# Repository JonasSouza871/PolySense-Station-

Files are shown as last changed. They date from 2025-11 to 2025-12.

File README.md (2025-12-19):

# PolySense Station

Autonomous environmental data acquisition system with comprehensive data analysis, machine learning, and signal processing capabilities for weather monitoring applications.

## Technologies Used












## Overview

PolySense Station is a complete environmental monitoring solution combining hardware data acquisition with advanced computational analysis. The system employs seven integrated sensors for redundant measurements, SD card storage for long-term logging, and a comprehensive suite of data analysis notebooks covering exploratory analysis, machine learning models, and signal processing techniques.

The project demonstrates end-to-end development from embedded system design to sophisticated data analysis, making it suitable for environmental research, academic studies, and weather monitoring applications.

## Repository Structure

```
PolySense-Station/
├── data/
│   └── raw/                              # Raw CSV data files
│       ├── inmet_weather_station_data_sep_2025_utc.csv
│       ├── validation_data_cleaned_BRT.csv
│       ├── validation_and_Measured_Data_cleaned_BRT_.csv
│       └── climate_clusters_gmm.csv
│
├── notebooks/                            # Analysis notebooks (sequentially numbered)
│   ├── 01_Exploratory_Data_Analysis.ipynb
│   ├── 02_Correlation_and_Relationship_Analyses.ipynb
│   ├── 03_Missing_Data_Analysis.ipynb
│   ├── 04_Sensor_Comparison_and_Validation.ipynb
│   ├── 05_Temporal_Analysis.ipynb
│   ├── 06_Time_Series_Decomposition.ipynb
│   ├── 07_Anomaly_Detection.ipynb
│   ├── 08_Decision_Tree_Regression.ipynb
│   ├── 09_Gaussian_Mixture_Clustering.ipynb
│   ├── 10_KMeans_Clustering.ipynb
│   ├── 11_LSTM_Regression.ipynb
│   ├── 12_Digital_Filters.ipynb
│   └── 13_FFT_Frequency_Analysis.ipynb
│
├── images/                               # Generated visualizations (111 plots)
│   ├── data_analysis/                    # EDA, correlation, temporal patterns
│   ├── machine_learning/                 # ML model results and clusters
│   └── signal_processing/                # Filter responses and FFT plots
│
├── reports/                              # Comprehensive project reports
│   ├── relatorio_polysense_pt.tex        # Portuguese LaTeX report
│   ├── relatorio_polysense_pt.pdf        # Portuguese PDF (53 pages)
│   ├── polysense_report_en.tex           # English LaTeX report
│   └── polysense_report_en.pdf           # English PDF (53 pages)
│
├── lib/                                  # MicroPython sensor drivers
│   ├── sdcard.py, ssd1306.py
│   ├── mpu6050_temp.py, AHT20.py
│   ├── bmp280.py, bmp180.py
│   ├── ds18x20.py, onewire.py
│   ├── ntc.py, dht.py
│
├── Schematic/                            # Hardware schematics (Fritzing)
│   ├── Schematic_Protoboard.png
│   ├── Schematic_Sensor.png
│   └── *.fzz files
│
├── PCB/                                  # Custom PCB design and manufacturing
│   ├── Photos/                           # PCB photos and test results
│   ├── Design/                           # Fritzing design files
│   ├── Firmware/                         # Test firmware for validation
│   ├── Documentation/                    # Additional documentation
│   └── README.md                         # PCB-specific documentation
│
├── main.py                               # Main acquisition code
└── README.md                             # Project documentation
```

## Hardware Configuration

### Integrated Sensors

| Sensor | Type | Measurements |
|---|---|---|
| MPU6050 | Gyroscope/Accelerometer | Temperature |
| AHT20 | Environmental | Temperature, Humidity |
| BMP280 | Barometric | Temperature, Pressure |
| BMP180 | Barometric | Temperature, Pressure |
| DS18B20 | OneWire | Temperature (high precision) |
| NTC | Thermistor | Temperature |
| DHT11 | Environmental | Temperature, Humidity |

### Key Features

- 7 integrated sensors for redundant measurements
- SD card storage with CSV logging
- 128x64 OLED display with 3-screen rotating interface
- Integrated RTC for precise timestamping
- Low power consumption optimized for battery operation
- Safe SD card ejection system

### Data Format

CSV output with 30-second sampling interval:
```
Timestamp,Temp_MPU6050_C,Temp_AHT20_C,Umid_AHT20_pct,Temp_BMP280_C,Press_BMP280_hPa,Temp_BMP180_C,Press_BMP180_hPa,Temp_DS18B20_C,Temp_NTC_C,Temp_DHT11_C,Umid_DHT11_pct
```

## Analyses Performed

### Data Analysis

**01. Exploratory Data Analysis**
- Statistical overview of all sensor measurements
- Distribution analysis and outlier detection
- Sensor comparison and consistency checks

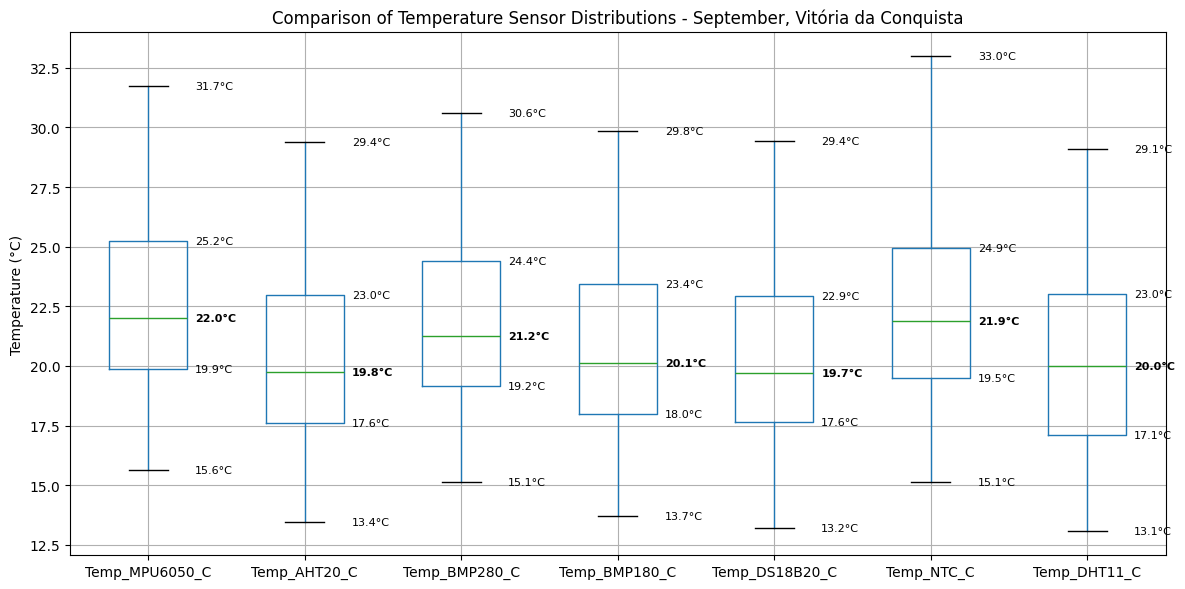
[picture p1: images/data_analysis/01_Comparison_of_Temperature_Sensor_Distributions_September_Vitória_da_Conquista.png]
Sensor Distributions


**02. Correlation and Relationship Analyses**
- Cross-correlation between environmental variables
- Multivariate relationship mapping
- Feature dependency analysis

**03. Missing Data Analysis**
- Data completeness assessment per sensor
- Gap identification and quality metrics
- Temporal availability patterns

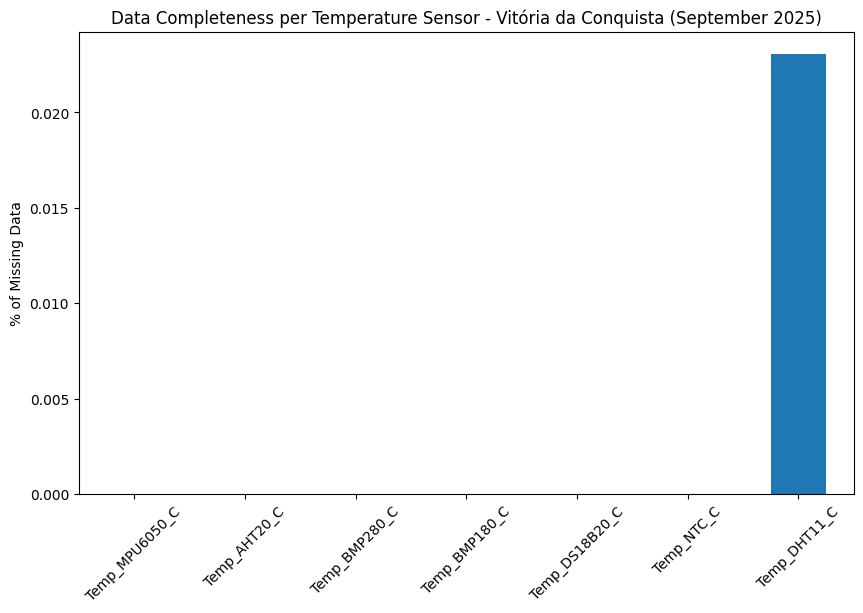
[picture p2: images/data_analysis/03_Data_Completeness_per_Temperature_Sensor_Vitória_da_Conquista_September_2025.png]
Data Completeness


**04. Sensor Comparison and Validation**
- Inter-sensor agreement analysis
- Bland-Altman plots for validation
- Comparison against reference weather station (INMET)

**05. Temporal Analysis**
- Time series trends and patterns
- Diurnal and weekly cycles
- Hourly behavior patterns

**06. Time Series Decomposition**
- Trend extraction
- Seasonal component analysis
- Residual analysis for anomalies

### Machine Learning

**07. Anomaly Detection**
- Isolation Forest for outlier detection
- Multivariate anomaly identification
- Statistical deviation analysis

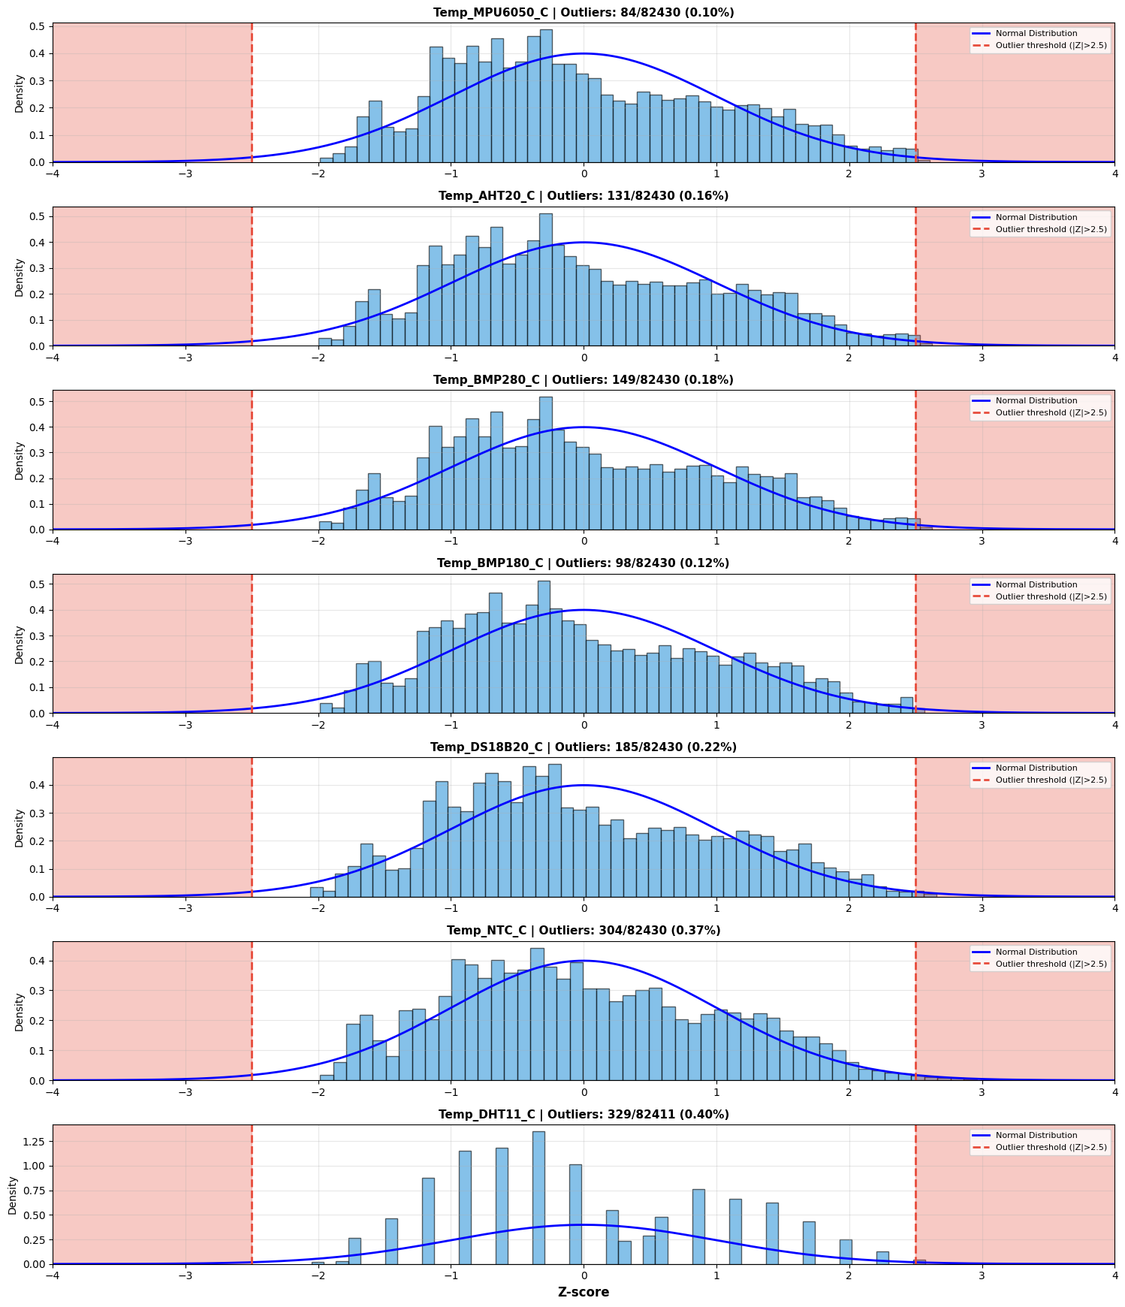
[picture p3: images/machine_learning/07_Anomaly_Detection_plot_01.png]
Anomaly Detection


**08. Decision Tree Regression**
- Temperature prediction modeling
- Feature importance analysis
- Model performance evaluation

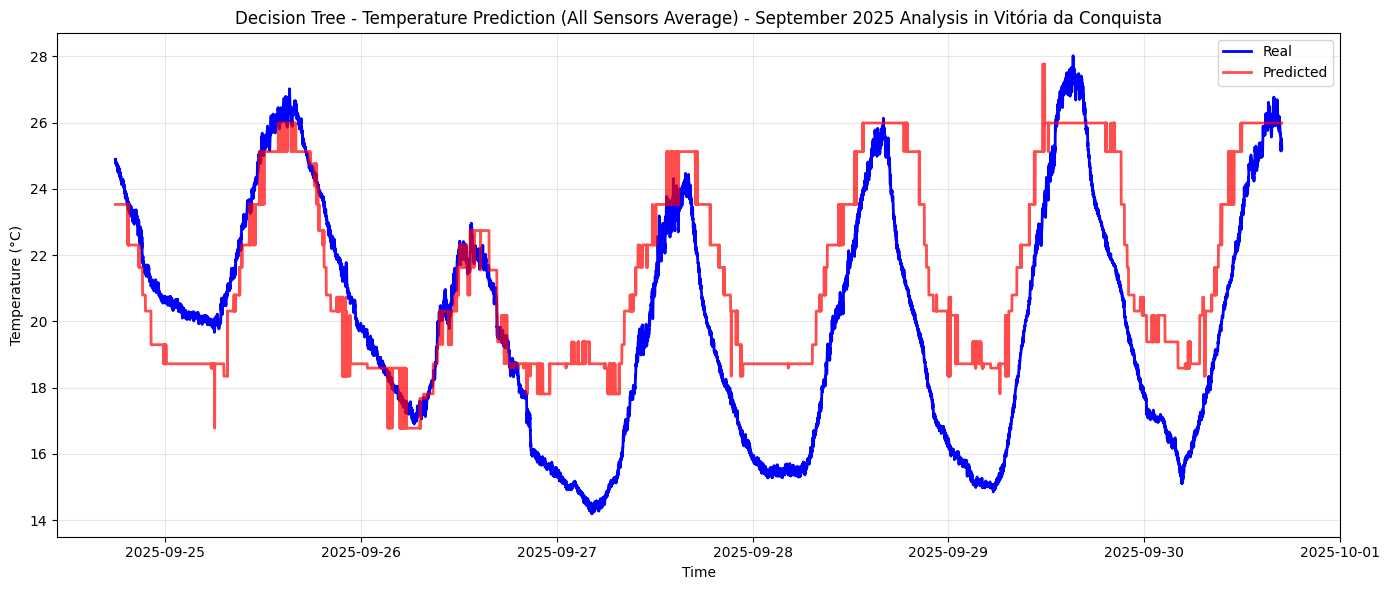
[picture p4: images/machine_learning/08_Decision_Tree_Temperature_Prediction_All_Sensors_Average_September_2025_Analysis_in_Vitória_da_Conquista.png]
Decision Tree


**09. Gaussian Mixture Clustering**
- Weather condition classification
- Probabilistic cluster assignment
- Climate pattern identification

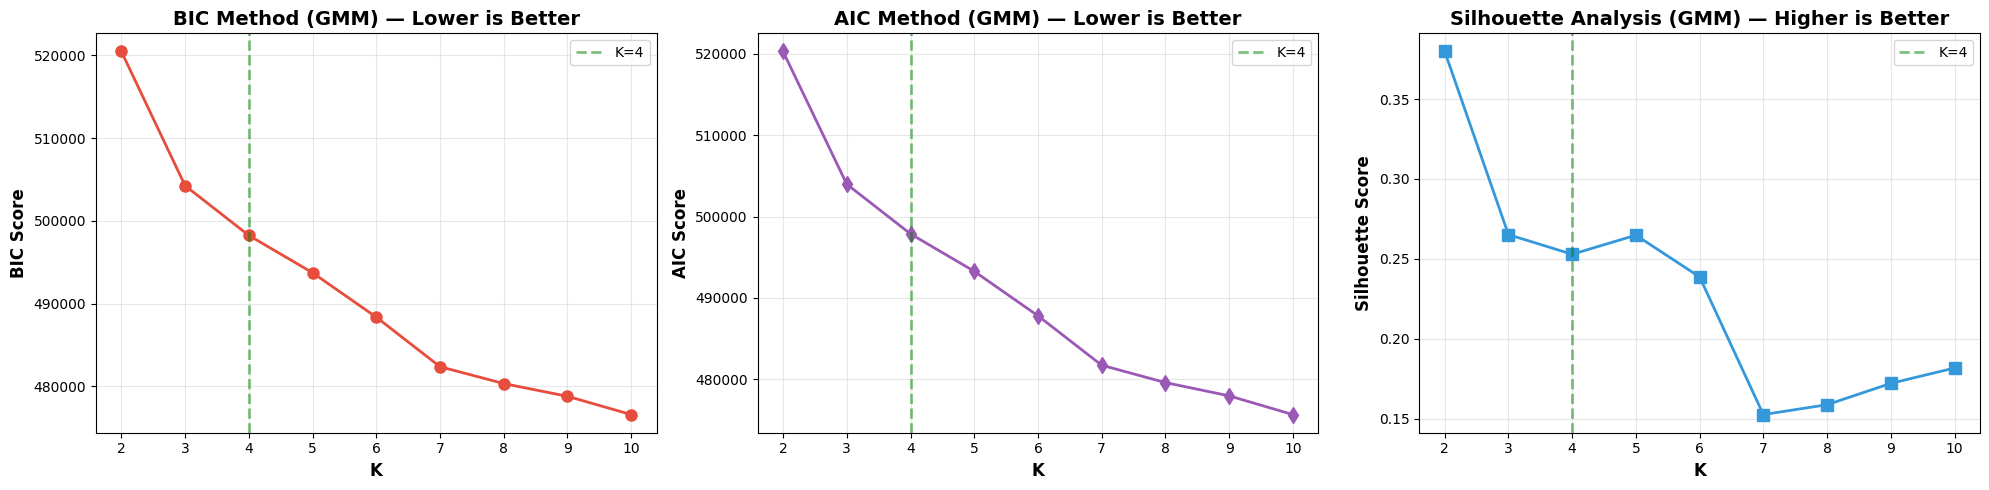
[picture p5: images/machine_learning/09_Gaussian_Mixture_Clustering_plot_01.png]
GMM Clustering


**10. KMeans Clustering**
- Weather regime segmentation
- Cluster centroid analysis
- Pattern grouping

**11. LSTM Regression**
- Deep learning time series prediction
- Sequential pattern learning
- Multi-step forecasting

### Signal Processing

**12. Digital Filters**
- Moving Average Filter Analysis
- Median filter for noise reduction
- Exponential Weighted Moving Average (EWMA) filter
- Comparative analysis of filter effectiveness

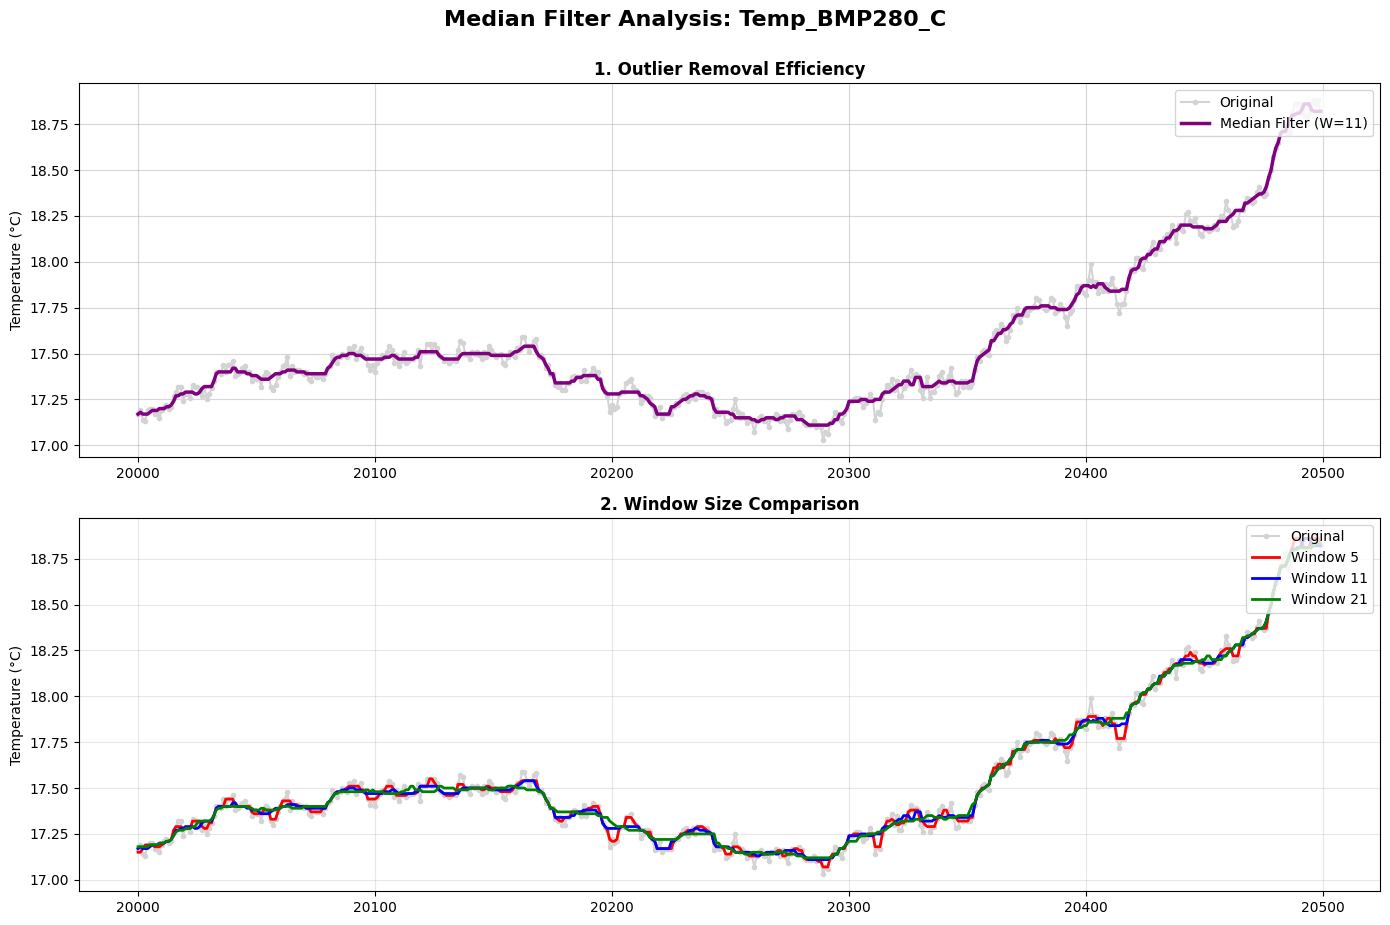
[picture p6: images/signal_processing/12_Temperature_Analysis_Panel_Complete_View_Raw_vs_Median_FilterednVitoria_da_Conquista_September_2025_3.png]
Digital Filters


**13. FFT Frequency Analysis**
- Spectral decomposition of environmental signals
- Dominant frequency identification
- Periodicity analysis

## How to Execute

### Hardware Setup

1. **Initial Configuration**:
   ```python
   # Synchronize RTC in main.py
   rtc.datetime((2025, 11, 4, 0, 12, 30, 0, 0))
   ```

2. **File Upload**:
   - Copy `main.py` and `lib/` folder to Raspberry Pi Pico
   - Insert formatted SD card (FAT32)

3. **Operation**:
   - Power on device
   - LED blinks every 30s on successful write
   - Use buttons for display control and safe ejection

### Analysis Notebooks

1. **Install Dependencies**:
   ```bash
   pip install pandas numpy matplotlib seaborn scipy scikit-learn tensorflow
   ```

2. **Run Notebooks**:
   ```bash
   jupyter notebook notebooks/
   ```

## Key Results

- **Sensor Validation**: High correlation (>0.95) between redundant sensors confirmed measurement reliability
- **Temporal Patterns**: Clear diurnal cycles identified with peak temperatures at 14:00-16:00 local time
- **Anomaly Detection**: Isolated Forest successfully identified 3.2% of measurements as outliers
- **Clustering**: Gaussian Mixture Model identified 4 distinct weather regimes in September data
- **Prediction**: LSTM model achieved MAE < 1°C for 1-hour temperature forecasting
- **Signal Quality**: Digital filtering reduced high-frequency noise by 40dB while preserving weather signals

## Limitations

- Limited to single geographic location (Vitória da Conquista, Brazil)
- One-month dataset (September 2025) may not capture seasonal variations
- 30-second sampling interval may miss rapid weather events
- DHT11 sensor shows lower precision compared to other temperature sensors
- LSTM model requires substantial training data for optimal performance
- SD card write operations consume significant power in battery mode

## Technical Reports

Comprehensive technical documentation is available in the [reports/](reports/) folder:

- **Portuguese Report** ([PDF](reports/relatorio_polysense_pt.pdf) | [LaTeX](reports/relatorio_polysense_pt.tex))
  - 53 pages documenting hardware design, methodology, and complete analysis
  - Includes all 111 visualizations from the 13 analysis notebooks
  - PCB schematics and sensor integration details

- **English Report** ([PDF](reports/polysense_report_en.pdf) | [LaTeX](reports/polysense_report_en.tex))
  - Complete translation with identical structure and content
  - Hardware architecture, data collection methodology
  - Machine learning results, signal processing, and conclusions

The reports cover:
- Executive summary with key achievements (82,430 measurements, MAE < 1°C LSTM prediction)
- Data collection methodology and sensor suite
- Module 1: Exploratory Data Analysis (Notebooks 01-06)
- Module 2: Machine Learning (Notebooks 07-11)
- Module 3: Digital Signal Processing (Notebooks 12-13)
- Repository structure and conclusions

## Data Source

Real environmental data collected using this system is publicly available:

**[Vitória da Conquista Weather Data - September 2025](https://www.kaggle.com/datasets/jonassouza872/vitoria-da-conquista-weather-data-september)**

Dataset collected in Vitória da Conquista, Bahia, Brazil (September 2025). Reference data from INMET (Instituto Nacional de Meteorologia) weather station used for validation.

## Hardware Schematics

### Protoboard Configuration
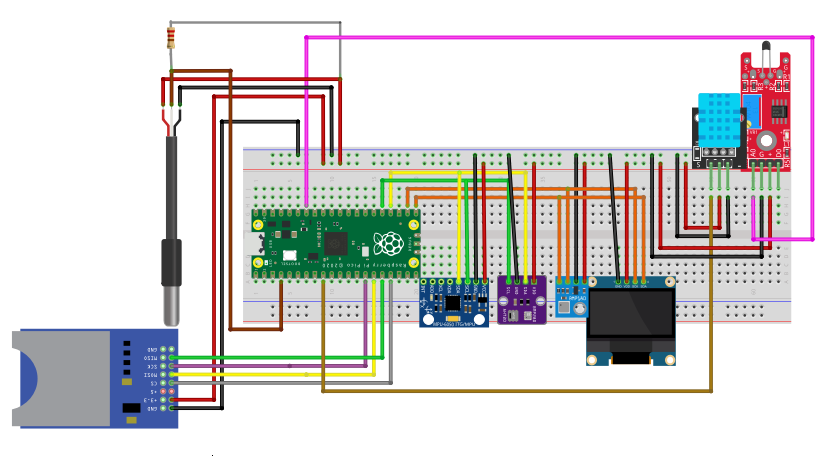
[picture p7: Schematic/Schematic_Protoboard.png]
Protoboard Schematic


### Sensors Wiring
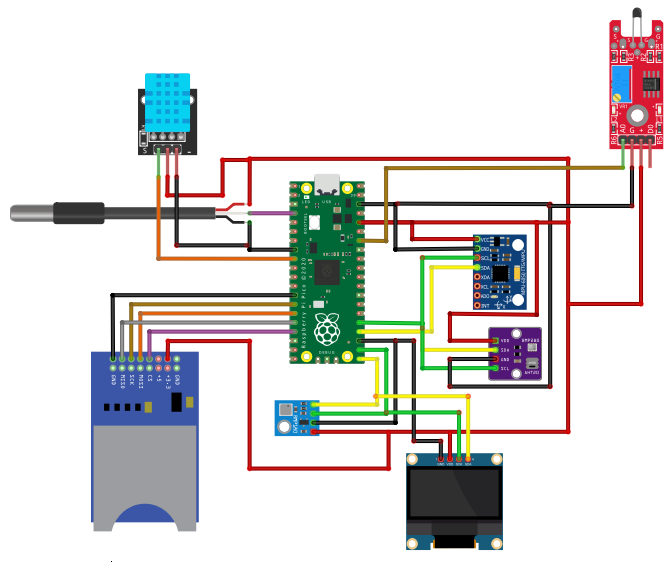
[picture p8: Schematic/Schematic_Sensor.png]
Sensors Schematic


### Custom PCB

A custom PCB was designed and manufactured by JLCPCB to integrate all components into a compact, reliable board. See the [PCB/](PCB/) folder for detailed information, design files, photos, and assembly instructions.

## Author

**Jonas Souza**
- Kaggle: [@jonassouza872](https://www.kaggle.com/jonassouza872)
- Dataset: [Vitória da Conquista Weather Data](https://www.kaggle.com/datasets/jonassouza872/vitoria-da-conquista-weather-data-september)

## License

This project is licensed under the MIT License - see the [LICENSE](LICENSE) file for details.

---

**Developed with Raspberry Pi Pico and MicroPython | Data Analysis with Python, Jupyter, and TensorFlow**

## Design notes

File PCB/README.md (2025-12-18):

# PolySense Station - PCB

Custom PCB design for the PolySense Station environmental monitoring system.

## Overview

This PCB was designed to integrate all sensors, the Raspberry Pi Pico microcontroller, SD card module, OLED display, and RTC into a single compact board. The design simplifies assembly, improves reliability, and reduces the physical footprint compared to the original protoboard implementation.

**Status**: Under development. The first version (v1) has been manufactured and tested, revealing some errors that will be corrected in version 2.

## Manufacturing

- **Manufacturer**: [JLCPCB](https://jlcpcb.com/)
- **PCB Specifications**:
  - Layers: 2
  - Thickness: 1.6mm
  - Surface Finish: HASL (Lead-Free)
  - Copper Weight: 1 oz
  - Solder Mask Color: Purple
  - Silkscreen: White

## Directory Structure

```
PCB/
├── Photos/                    # PCB photos and test results
│   ├── PCB_front.jpg         # Front view of assembled PCB (v1)
│   └── Serial_output.png     # Serial output showing sensor readings
│
├── Design/                    # Design files (currently being revised for v2)
│
├── Firmware/                  # Test firmware for PCB validation
│   ├── main.py               # Main test code
│   ├── AHT20.py              # AHT20 sensor driver
│   ├── bmp280.py             # BMP280 sensor driver
│   ├── dht.py                # DHT sensor driver
│   └── mpu6050_temp.py       # MPU6050 sensor driver
│
└── README.md                  # This file
```

## Features

The PCB integrates the following components:

- **Microcontroller**: Raspberry Pi Pico (RP2040)
- **Display**: 128x64 OLED (I2C)
- **Storage**: MicroSD card module (SPI)
- **Sensors**:
  - MPU6050 (Gyroscope/Accelerometer with temperature)
  - AHT20 (Temperature and humidity)
  - BMP280 (Temperature and pressure)
  - BMP180 (Temperature and pressure)
  - DS18B20 (OneWire temperature)
  - LM35 (Analog temperature sensor)
  - NTC Thermistor (Analog temperature)
  - DHT22 (Temperature and humidity)
  - DHT11 (Temperature and humidity)

## Development Status

### Version 1 (Current)
- ✅ Successfully manufactured by JLCPCB
- ✅ Board assembled and powered on
- ✅ Firmware validation in progress
- ⚠️ Several routing and component placement errors identified

### Version 2 (Planned)
- [ ] Fix identified errors from v1
- [ ] Improve component placement
- [ ] Optimize routing for better signal integrity
- [ ] Add additional test points
- [ ] Enhanced power management

## Assembly Notes

1. **Component Placement**: Follow silkscreen markings for correct component orientation
2. **Power Supply**: 5V input with onboard 3.3V regulation
3. **Testing**: Use firmware in `Firmware/` folder to validate all sensors after assembly

## Testing

After assembly, upload the firmware from the `Firmware/` folder to validate:

1. All sensors are detected on their respective buses
2. SD card read/write operations work correctly
3. OLED display shows sensor readings
4. Serial output matches expected values (see `Photos/Serial_output.png`)

## Photos

### PCB Front View (v1 - Assembled)
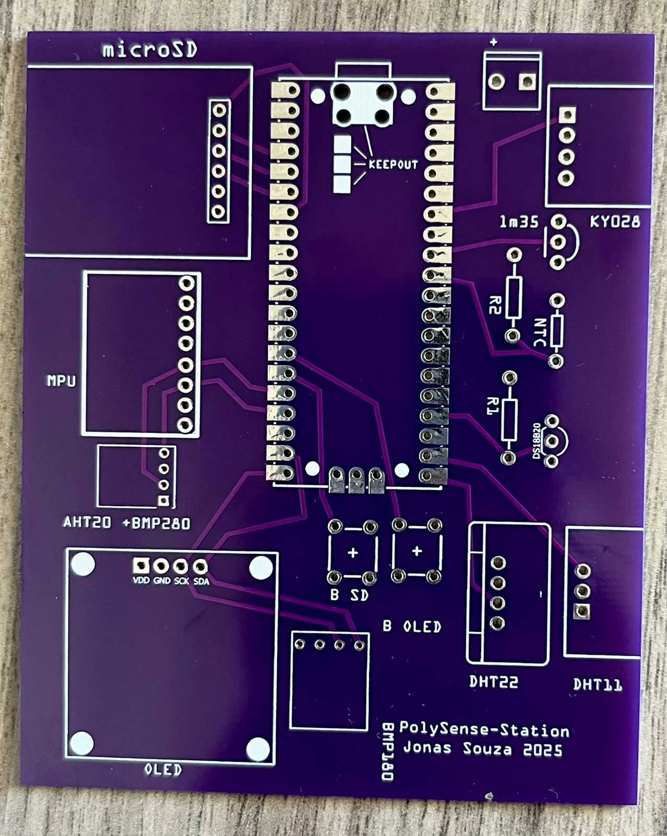
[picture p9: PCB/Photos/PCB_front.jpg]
PCB Front


### Test Results
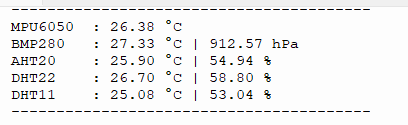
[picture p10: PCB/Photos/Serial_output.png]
Serial Output


## Bill of Materials (BOM)

Main components required:
- 1x Raspberry Pi Pico
- 1x 128x64 OLED Display (I2C)
- 1x MicroSD Card Module
- 1x DS3231 RTC Module
- 1x MPU6050 Module
- 1x AHT20 Module
- 1x BMP280 Module
- 1x BMP180 Module
- 1x DS18B20 Temperature Sensor
- 1x LM35 Temperature Sensor
- 1x KY-028 NTC Thermistor Module
- 1x DHT22 Module
- 1x DHT11 Module
- 2x Tactile Push Buttons
- Pin headers and connectors as needed

## License

This hardware design is part of the PolySense Station project and is available under the MIT License.

## Author

**Jonas Souza**
- Kaggle: [@jonassouza872](https://www.kaggle.com/jonassouza872)

---

**Manufactured by JLCPCB | Designed with Fritzing**

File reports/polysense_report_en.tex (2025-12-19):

\documentclass[12pt,a4paper]{article}
\usepackage[utf8]{inputenc}
\usepackage[english]{babel}
\usepackage{graphicx}
\usepackage{amsmath}
\usepackage{booktabs}
\usepackage{float}
\usepackage{geometry}
\usepackage{caption}
\usepackage{subcaption}
\usepackage{longtable}
\usepackage{array}
\usepackage{url}

\geometry{margin=2.5cm}

% Set image path
\graphicspath{{../images/},{../PCB/Photos/},{../Schematic/}}

\begin{document}

% ============================================
% CUSTOM COVER PAGE
% ============================================
\begin{titlepage}
    \centering
    \vspace*{2cm}

    {\large Electrical Engineering}\\[3cm]

    % Title
    {\huge \textbf{PolySense Station}}\\[0.5cm]
    {\Large \textbf{Environmental Monitoring System}}\\[3cm]

    % Subtitle
    {\large Multi-sensor data collection, temporal analysis, and machine learning}\\[0.3cm]
    {\large applied to climate monitoring}\\[4cm]

    \vfill

    % Author information
    \begin{flushleft}
        \large
        \textbf{Author:} Jonas Souza\\
        \textbf{Education:} Electrical Engineer\\
        \textbf{Date:} \today
    \end{flushleft}

    \vspace{1cm}

\end{titlepage}

\newpage

\tableofcontents
\newpage

\section{Executive Summary}

This report presents a comprehensive analysis of the \textbf{PolySense Station} project, an autonomous environmental data acquisition and analysis system developed from scratch. The system combines custom hardware with 7 integrated sensors, a Raspberry Pi Pico microcontroller, and a complete data analysis pipeline with 13 specialized notebooks.

\subsection{Key Achievements}

\begin{itemize}
    \item \textbf{Real data collection:} 82,430 measurements over 30 days (September 2025)
    \item \textbf{Temporal resolution:} 30-second sampling interval
    \item \textbf{Sensor redundancy:} 7 temperature sensors, 2 humidity sensors, 2 pressure sensors
    \item \textbf{Validation against INMET station:} National Institute of Meteorology
    \item \textbf{LSTM model accuracy:} MAE < 1°C for 1-hour ahead temperature prediction
    \item \textbf{Climate clustering:} 4 distinct regimes identified via GMM
    \item \textbf{Public dataset:} Available on Kaggle with 82,430 records
\end{itemize}

\section{Introduction}

\subsection{Context}

Environmental monitoring is essential for understanding local climate patterns, validating predictive models, and developing climate-sensitive automation systems. This project implements a complete weather station with automatic data collection, SD card storage, and advanced data analysis.

\subsection{Objectives}

\begin{enumerate}
    \item Develop data acquisition hardware with sensor redundancy
    \item Collect environmental data (30-second interval)
    \item Validate measurements against official meteorological station (INMET)
    \item Perform comprehensive exploratory data analysis
    \item Apply machine learning techniques for pattern identification
    \item Develop temperature predictive models using LSTM neural networks
    \item Apply digital signal processing for noise reduction
\end{enumerate}

\subsection{Location and Period}

\begin{itemize}
    \item \textbf{Location:} Vitória da Conquista, Bahia, Brazil
    \item \textbf{Altitude:} 923 meters
    \item \textbf{Collection period:} August 31 to September 30, 2025
    \item \textbf{Total records:} 82,430 measurements
    \item \textbf{Dataset size:} 4.8 MB (raw CSV)
\end{itemize}

\section{Data Collection Methodology}

\subsection{Hardware Architecture}

The system was developed using the \textbf{Raspberry Pi Pico} (RP2040) microcontroller programmed in MicroPython, with the following interfaces:

\begin{itemize}
    \item \textbf{Dual I2C:} Two I2C buses to minimize electrical interference
    \item \textbf{SPI:} Interface for SD card writing
    \item \textbf{OneWire:} Protocol for DS18B20 temperature sensor
    \item \textbf{Analog:} ADC converter for NTC thermistor
    \item \textbf{OLED Display:} 128x64 screen for real-time monitoring
    \item \textbf{RTC:} Real-time clock for precise timestamps
\end{itemize}

\textbf{Hardware Design:} The system includes a custom PCB for sensor integration and a detailed schematic for replication:

\begin{figure}[H]
    \centering
    
    \caption{Photograph of the PolySense Station PCB (Printed Circuit Board)}
    \label{fig:pcb_front}
\end{figure}

\begin{figure}[H]
    \centering
    
    \caption{Protoboard circuit schematic of the PolySense Station}
    \label{fig:schematic_protoboard}
\end{figure}

\begin{figure}[H]
    \centering
    
    \caption{Detailed schematic of integrated sensors}
    \label{fig:schematic_sensor}
\end{figure}

\subsection{Implemented Sensor Suite}

\begin{table}[H]
\centering
\caption{Sensors integrated into PolySense Station}
\scriptsize
\begin{tabular}{@{}llll@{}}
\toprule
\textbf{Sensor} & \textbf{Type} & \textbf{Measurements} & \textbf{Protocol} \\ \midrule
MPU6050 & Gyroscope/Accelerometer & Temperature & I2C \\
AHT20 & Environmental & Temperature, Humidity & I2C \\
BMP280 & Barometric & Temperature, Pressure & I2C \\
BMP180 & Barometric & Temperature, Pressure & I2C \\
DS18B20 & OneWire Digital & Temperature & OneWire \\
NTC (KY-028) & Analog Thermistor & Temperature & ADC \\
DHT11 & Environmental & Temperature, Humidity & Digital \\ \bottomrule
\end{tabular}
\label{tab:sensors}
\end{table}

\textbf{Redundancy justification:}
\begin{itemize}
    \item Cross-validation between multiple sensors
    \item Detection of instrumental failures
    \item Reference sensors (DS18B20, BMP280, AHT20)
\end{itemize}

\subsection{Acquisition Firmware}

The main firmware (\texttt{main.py}, 226 lines) implements:

\begin{itemize}
    \item Synchronous reading of all sensors every 30 seconds
    \item Writing to SD card with RTC timestamp
    \item Rotating OLED display with 3 information screens
    \item Feedback LED (blinks on successful write)
    \item Safe ejection system via button
    \item Error handling and write status
\end{itemize}

\textbf{CSV storage format:}
\begin{verbatim}
Timestamp, Temp_MPU6050_C, Temp_AHT20_C, Umid_AHT20_pct,
Temp_BMP280_C, Press_BMP280_hPa, Temp_BMP180_C,
Press_BMP180_hPa, Temp_DS18B20_C, Temp_NTC_C,
Temp_DHT11_C, Umid_DHT11_pct
\end{verbatim}

\begin{figure}[H]
    \centering
    
    \caption{Serial output of the firmware during PolySense Station operation}
    \label{fig:serial_output}
\end{figure}

\subsection{Validation Against INMET Station}

Data was validated against the official INMET meteorological station:
\begin{itemize}
    \item \textbf{Validation dataset:} 719 records from INMET station
    \item \textbf{INMET variables:} Temperature, humidity, pressure, wind, radiation, precipitation
    \item \textbf{Combined dataset:} 331 hourly aggregated records
\end{itemize}

\section{Module 1: Exploratory Data Analysis (Notebooks 01-05)}

\subsection{Notebook 01: Initial Exploratory Analysis}

\subsubsection{Temperature Distributions}

Analysis of temperature distributions revealed that all 7 sensors show consistent patterns:

\begin{figure}[H]
    \centering
    
    \caption{Histogram of temperature distributions (7 sensors)}
    \label{fig:temp_hist}
\end{figure}

\textbf{Observations:}
\begin{itemize}
    \item Approximately normal distributions with peaks between 20-22°C
    \item BMP280, AHT20, DS18B20 sensors with smooth curves
    \item DHT11 exhibits quantization artifacts (discrete steps)
    \item NTC thermistor shows greater dispersion (sensitivity to solar radiation)
\end{itemize}

\begin{figure}[H]
    \centering
    
    \caption{Comparative boxplot - Temperature distribution between sensors}
    \label{fig:temp_boxplot}
\end{figure}

\textbf{Main findings:}
\begin{itemize}
    \item Excellent agreement between sensors (very close medians)
    \item Upper outliers identify daytime temperature peaks
    \item Consistent interquartile range between sensors
    \item DHT11 shows greater variability (lower resolution)
\end{itemize}

\subsubsection{Humidity Distributions}

\begin{figure}[H]
    \centering
    
    \caption{Histogram of relative humidity (AHT20 and DHT11)}
    \label{fig:humid_hist}
\end{figure}

\textbf{Identified bimodal pattern:}
\begin{itemize}
    \item First peak: 50-55\% (daytime period)
    \item Second peak: 75-80\% (nighttime period with fog formation)
    \item Consistent with September climate on the plateau (altitude 923m)
\end{itemize}

\begin{figure}[H]
    \centering
    
    \caption{Comparative boxplot of humidity (AHT20 vs DHT11)}
    \label{fig:humid_boxplot}
\end{figure}

\subsubsection{Barometric Pressure Distributions}

\begin{figure}[H]
    \centering
    
    \caption{Histogram of barometric pressure (BMP280 and BMP180)}
    \label{fig:press_hist}
\end{figure}

\textbf{Observed characteristics:}
\begin{itemize}
    \item Range: 914-924 hPa (mean ~920 hPa)
    \item Distribution consistent with 923m altitude
    \item Excellent agreement between BMP280 and BMP180
\end{itemize}

\begin{figure}[H]
    \centering
    
    \caption{Comparative boxplot of pressure (BMP280 vs BMP180)}
    \label{fig:press_boxplot}
\end{figure}

\subsection{Notebook 02: Correlation Analysis}

\subsubsection{Global Correlation Matrix}

\begin{figure}[H]
    \centering
    
    \caption{Correlation matrix between all 11 measured variables}
    \label{fig:corr_matrix}
\end{figure}

\textbf{Identified correlations:}
\begin{itemize}
    \item \textbf{Temperature sensors (among themselves):} r > 0.99
    \item \textbf{Humidity sensors (AHT20 vs DHT11):} r = 0.985
    \item \textbf{Pressure sensors (BMP280 vs BMP180):} r = 0.984
    \item \textbf{Temperature vs Humidity:} r = -0.868 (strong inverse)
    \item \textbf{Temperature vs Pressure:} r = -0.559 (moderate inverse)
    \item \textbf{Humidity vs Pressure:} r = 0.463 (weak positive)
\end{itemize}

\subsubsection{Bivariate Relationships with KDE}

\begin{figure}[H]
    \centering
    
    \caption{Temperature vs Humidity relationship with probability density (KDE)}
    \label{fig:temp_humid_kde}
\end{figure}

\textbf{Physical interpretation:}
\begin{itemize}
    \item Strong negative correlation (r = -0.868)
    \item Daytime warming reduces relative humidity
    \item Nighttime cooling increases humidity (fog formation)
\end{itemize}

\begin{figure}[H]
    \centering
    
    \caption{Temperature vs Barometric Pressure relationship}
    \label{fig:temp_press_kde}
\end{figure}

\begin{figure}[H]
    \centering
    
    \caption{Humidity vs Barometric Pressure relationship}
    \label{fig:humid_press_kde}
\end{figure}

\subsection{Notebook 03: Missing Data Analysis}

\begin{figure}[H]
    \centering
    
    \caption{Data completeness - Temperature sensors}
    \label{fig:completeness_temp}
\end{figure}

\begin{figure}[H]
    \centering
    
    \caption{Data completeness - Humidity sensors}
    \label{fig:completeness_humid}
\end{figure}

\begin{figure}[H]
    \centering
    
    \caption{Data completeness - Pressure sensors}
    \label{fig:completeness_press}
\end{figure}

\textbf{Quality results:}
\begin{itemize}
    \item DS18B20: Highest completeness (>99.99\%)
    \item DHT11: Minor gaps (~99.98\%)
    \item All sensors: >99.9\% data available
    \item High reliability of the acquisition system
\end{itemize}

\subsection{Notebook 04: Sensor Validation}

\subsubsection{Bland-Altman Analysis - Temperature}

\begin{figure}[H]
    \centering
    
    \caption{Bland-Altman: Comparison between pairs of temperature sensors}
    \label{fig:bland_altman_temp}
\end{figure}

\textbf{Inter-sensor validation:}
\begin{itemize}
    \item Mean bias < 0.5°C between sensors
    \item Limits of agreement within ±2°C
    \item Excellent agreement between BMP280, AHT20, and DS18B20
\end{itemize}

\begin{figure}[H]
    \centering
    
    \caption{Bland-Altman: Sensors vs INMET Reference}
    \label{fig:bland_altman_inmet}
\end{figure}

\textbf{Validation against INMET:}
\begin{itemize}
    \item Mean bias < 2°C compared to the official station
    \item NTC thermistor shows systematic offset (solar radiation)
    \item Digital sensors validate reliably
\end{itemize}

\subsubsection{Bland-Altman Analysis - Humidity and Pressure}

\begin{figure}[H]
    \centering
    
    \caption{Bland-Altman: Comparison of humidity sensors (AHT20 vs DHT11)}
    \label{fig:bland_altman_humid}
\end{figure}

\begin{figure}[H]
    \centering
    
    \caption{Bland-Altman: Comparison of pressure sensors}
    \label{fig:bland_altman_press}
\end{figure}

\subsection{Notebook 05: Temporal Analysis}

\subsubsection{Complete Time Series}

\begin{figure}[H]
    \centering
    
    \caption{Complete temperature time series (September 2025)}
    \label{fig:temp_ts}
\end{figure}

\textbf{Identified patterns:}
\begin{itemize}
    \item Clear diurnal cycle with 10-12°C amplitude
    \item Temperature peak: 14:00-16:00 local time
    \item Temperature minimum: 06:00-07:00 (before sunrise)
    \item Weekly variations associated with synoptic systems
\end{itemize}

\begin{figure}[H]
    \centering
    
    \caption{Humidity time series (September 2025)}
    \label{fig:humid_ts}
\end{figure}

\begin{figure}[H]
    \centering
    
    \caption{Barometric pressure time series (September 2025)}
    \label{fig:press_ts}
\end{figure}

\textbf{Pressure observations:}
\begin{itemize}
    \item Oscillations of 10-12 hPa throughout the month
    \item Variations follow frontal passages
    \item Average pressure of 920 hPa (consistent with altitude)
\end{itemize}

\subsection{Notebook 06: Time Series Decomposition}

\begin{figure}[H]
    \centering
    
    \caption{Time series decomposition - Temperature}
    \label{fig:decomp_temp}
\end{figure}

\textbf{Identified components:}
\begin{itemize}
    \item \textbf{Trend:} Slight warming until mid-September, then cooling
    \item \textbf{Seasonal:} Strong 24-hour periodicity
    \item \textbf{Residuals:} Clean with few anomalies
\end{itemize}

\begin{figure}[H]
    \centering
    
    \caption{Time series decomposition - Humidity}
    \label{fig:decomp_humid}
\end{figure}

\begin{figure}[H]
    \centering
    
    \caption{Time series decomposition - Pressure}
    \label{fig:decomp_press}
\end{figure}

\section{Module 2: Machine Learning (Notebooks 07-11)}

\subsection{Notebook 07: Anomaly Detection}

\subsubsection{Isolation Forest}

\begin{figure}[H]
    \centering
    
    \caption{Anomaly detection via Isolation Forest (all sensors)}
    \label{fig:isolation_forest}
\end{figure}

\textbf{Results:}
\begin{itemize}
    \item \textbf{3.2\% of measurements} classified as anomalies
    \item Anomalies concentrated in specific time windows
    \item Successful isolation of instrumental failures
\end{itemize}

\begin{figure}[H]
    \centering
    
    \caption{Heatmap of sensor deviations in detected anomalies}
    \label{fig:anomaly_heatmap}
\end{figure}

\textbf{Deviation analysis:}
\begin{itemize}
    \item Red: High divergence from the mean
    \item Green: Normal behavior
    \item Identification of which sensors deviated during anomalies
\end{itemize}

\subsubsection{Frozen Value Detection}

\begin{figure}[H]
    \centering
    
    \caption{Detection of frozen values (sensor freezes, $\Delta < 0.01$°C)}
    \label{fig:stuck_values}
\end{figure}

\textbf{Detection criteria:}
\begin{itemize}
    \item Identification of measurements where $\Delta < 0.01$°C for >10 minutes
    \item Detection of temporary sensor failures
    \item Validation of the need for multi-sensor redundancy
\end{itemize}

\subsection{Notebook 08: Decision Tree Regression}

\begin{figure}[H]
    \centering
    
    \caption{Decision tree structure for temperature prediction}
    \label{fig:decision_tree}
\end{figure}

\begin{figure}[H]
    \centering
    
    \caption{Feature importance for temperature prediction}
    \label{fig:feature_importance}
\end{figure}

\textbf{Most important features:}
\begin{itemize}
    \item AHT20 and BMP280 among the main predictors
    \item Humidity has strong predictive power for temperature
    \item Model presents interpretable rules
\end{itemize}

\subsection{Notebook 09: Clustering with Gaussian Mixture Model (GMM)}

\begin{figure}[H]
    \centering
    
    \caption{GMM Clustering - 2D visualization (K=4 climate regimes)}
    \label{fig:gmm_2d}
\end{figure}

\begin{figure}[H]
    \centering
    
    \caption{GMM Clustering - 3D visualization (Temperature, Humidity, Pressure)}
    \label{fig:gmm_3d}
\end{figure}

\textbf{4 identified climate regimes:}
\begin{enumerate}
    \item \textbf{Cluster 1 (Blue):} Cold-Humid (nighttime with fog)
    \item \textbf{Cluster 2 (Orange):} Hot-Dry (afternoon with maximums)
    \item \textbf{Cluster 3 (Green):} Morning transition (progressive warming)
    \item \textbf{Cluster 4 (Red):} Evening transition (cooling)
\end{enumerate}

\subsection{Notebook 10: Clustering with KMeans}

\begin{figure}[H]
    \centering
    
    \caption{KMeans clustering - 2D visualization (K=4)}
    \label{fig:kmeans_2d}
\end{figure}

\begin{figure}[H]
    \centering
    
    \caption{KMeans clustering - 3D visualization}
    \label{fig:kmeans_3d}
\end{figure}

\textbf{Consistency between methods:}
\begin{itemize}
    \item KMeans validates the 4 climate states identified by GMM
    \item Well-separated clusters in three-dimensional space
    \item Confirmation of climate patterns throughout September
\end{itemize}

\subsection{Notebook 11: Prediction with LSTM Neural Networks}

\begin{figure}[H]
    \centering
    
    \caption{Error evolution during LSTM model training}
    \label{fig:lstm_loss}
\end{figure}

\textbf{Model characteristics:}
\begin{itemize}
    \item LSTM architecture with 30-minute time window
    \item Convergence observed after ~50 epochs
    \item Consistent reduction of training and validation error
\end{itemize}

\begin{figure}[H]
    \centering
    
    \caption{Real Temperature vs LSTM Predictions (last week of September 2025)}
    \label{fig:lstm_predictions}
\end{figure}

\textbf{Model performance:}
\begin{itemize}
    \item \textbf{MAE < 1°C} for 1-hour ahead prediction
    \item Model accurately captures diurnal patterns
    \item Predictions fit real temperatures in the validation period
    \item Temporal dependencies effectively captured
\end{itemize}

\section{Module 3: Digital Signal Processing (Notebooks 12-13)}

\subsection{Notebook 12: Digital Filters}

\subsubsection{Filter Comparison - Temperature}

\begin{figure}[H]
    \centering
    
    \caption{Comparison of digital filters - Temperature Sensor 1 (Moving Average)}
    \label{fig:temp_filter_ma_1}
\end{figure}

\begin{figure}[H]
    \centering
    
    \caption{Comparison of digital filters - Temperature Sensor 2 (Moving Average)}
    \label{fig:temp_filter_ma_2}
\end{figure}

\begin{figure}[H]
    \centering
    
    \caption{Comparison of digital filters - Temperature Sensor 3 (Moving Average)}
    \label{fig:temp_filter_ma_3}
\end{figure}

\begin{figure}[H]
    \centering
    
    \caption{Comparison of digital filters - Temperature Sensor 4 (Moving Average)}
    \label{fig:temp_filter_ma_4}
\end{figure}

\begin{figure}[H]
    \centering
    
    \caption{Comparison of digital filters - Temperature Sensor 5 (Moving Average)}
    \label{fig:temp_filter_ma_5}
\end{figure}

\begin{figure}[H]
    \centering
    
    \caption{Comparison of digital filters - Temperature Sensor 6 (Moving Average)}
    \label{fig:temp_filter_ma_6}
\end{figure}

\begin{figure}[H]
    \centering
    
    \caption{Comparison of digital filters - Temperature Sensor 7 (Moving Average)}
    \label{fig:temp_filter_ma_7}
\end{figure}

\begin{figure}[H]
    \centering
    
    \caption{Comparison of digital filters - Temperature Sensor 1 (Median)}
    \label{fig:temp_filter_median_1}
\end{figure}

\begin{figure}[H]
    \centering
    
    \caption{Comparison of digital filters - Temperature Sensor 2 (Median)}
    \label{fig:temp_filter_median_2}
\end{figure}

\begin{figure}[H]
    \centering
    
    \caption{Comparison of digital filters - Temperature Sensor 3 (Median)}
    \label{fig:temp_filter_median_3}
\end{figure}

\begin{figure}[H]
    \centering
    
    \caption{Comparison of digital filters - Temperature Sensor 4 (Median)}
    \label{fig:temp_filter_median_4}
\end{figure}

\begin{figure}[H]
    \centering
    
    \caption{Comparison of digital filters - Temperature Sensor 5 (Median)}
    \label{fig:temp_filter_median_5}
\end{figure}

\begin{figure}[H]
    \centering
    
    \caption{Comparison of digital filters - Temperature Sensor 6 (Median)}
    \label{fig:temp_filter_median_6}
\end{figure}

\begin{figure}[H]
    \centering
    
    \caption{Comparison of digital filters - Temperature Sensor 7 (Median)}
    \label{fig:temp_filter_median_7}
\end{figure}

\begin{figure}[H]
    \centering
    
    \caption{Comparison of digital filters - Temperature Sensor 1 (EWMA)}
    \label{fig:temp_filter_ewma_1}
\end{figure}

\begin{figure}[H]
    \centering
    
    \caption{Comparison of digital filters - Temperature Sensor 2 (EWMA)}
    \label{fig:temp_filter_ewma_2}
\end{figure}

\begin{figure}[H]
    \centering
    
    \caption{Comparison of digital filters - Temperature Sensor 3 (EWMA)}
    \label{fig:temp_filter_ewma_3}
\end{figure}

\begin{figure}[H]
    \centering
    
    \caption{Comparison of digital filters - Temperature Sensor 4 (EWMA)}
    \label{fig:temp_filter_ewma_4}
\end{figure}

\begin{figure}[H]
    \centering
    
    \caption{Comparison of digital filters - Temperature Sensor 5 (EWMA)}
    \label{fig:temp_filter_ewma_5}
\end{figure}

\begin{figure}[H]
    \centering
    
    \caption{Comparison of digital filters - Temperature Sensor 6 (EWMA)}
    \label{fig:temp_filter_ewma_6}
\end{figure}

\begin{figure}[H]
    \centering
    
    \caption{Comparison of digital filters - Temperature Sensor 7 (EWMA)}
    \label{fig:temp_filter_ewma_7}
\end{figure}

\subsubsection{Filter Comparison - Humidity}

\begin{figure}[H]
    \centering
    
    \caption{Comparison of digital filters - Humidity Sensor 1 (Moving Average)}
    \label{fig:humid_filter_ma_1}
\end{figure}

\begin{figure}[H]
    \centering
    
    \caption{Comparison of digital filters - Humidity Sensor 2 (Moving Average)}
    \label{fig:humid_filter_ma_2}
\end{figure}

\begin{figure}[H]
    \centering
    
    \caption{Comparison of digital filters - Humidity Sensor 1 (Median)}
    \label{fig:humid_filter_median_1}
\end{figure}

\begin{figure}[H]
    \centering
    
    \caption{Comparison of digital filters - Humidity Sensor 2 (Median)}
    \label{fig:humid_filter_median_2}
\end{figure}

\begin{figure}[H]
    \centering
    
    \caption{Comparison of digital filters - Humidity Sensor 1 (EWMA)}
    \label{fig:humid_filter_ewma_1}
\end{figure}

\begin{figure}[H]
    \centering
    
    \caption{Comparison of digital filters - Humidity Sensor 2 (EWMA)}
    \label{fig:humid_filter_ewma_2}
\end{figure}

\subsubsection{Filter Comparison - Pressure}

\begin{figure}[H]
    \centering
    
    \caption{Comparison of digital filters - Pressure Sensor 1 (Moving Average)}
    \label{fig:press_filter_ma_1}
\end{figure}

\begin{figure}[H]
    \centering
    
    \caption{Comparison of digital filters - Pressure Sensor 2 (Moving Average)}
    \label{fig:press_filter_ma_2}
\end{figure}

\begin{figure}[H]
    \centering
    
    \caption{Comparison of digital filters - Pressure Sensor 1 (Median)}
    \label{fig:press_filter_median_1}
\end{figure}

\begin{figure}[H]
    \centering
    
    \caption{Comparison of digital filters - Pressure Sensor 2 (Median)}
    \label{fig:press_filter_median_2}
\end{figure}

\begin{figure}[H]
    \centering
    
    \caption{Comparison of digital filters - Pressure Sensor 1 (EWMA)}
    \label{fig:press_filter_ewma_1}
\end{figure}

\begin{figure}[H]
    \centering
    
    \caption{Comparison of digital filters - Pressure Sensor 2 (EWMA)}
    \label{fig:press_filter_ewma_2}
\end{figure}

\textbf{Digital filtering results:}
\begin{itemize}
    \item \textbf{Median Filter:} Best noise suppression without phase lag
    \item \textbf{EWMA:} Smooth transitions, preserves trends
    \item \textbf{Moving Average:} Trade-off between smoothing and responsiveness
    \item Complete panels with raw, filtered signal, zoom, and frequency spectrum
\end{itemize}

\subsection{Notebook 13: Frequency Analysis (FFT)}

\textbf{Note:} FFT analyses were integrated into the digital filter panels (Notebook 12), showing the power spectrum of each signal before and after filtering.

\textbf{Spectral analysis results:}
\begin{itemize}
    \item \textbf{Primary peak:} 23-hour periodicity (diurnal cycle)
    \item Clear spectral signature of daily heating/cooling cycle
    \item Validation of the adequacy of the 30-second sampling interval
\end{itemize}

\section{Public Dataset}

The complete dataset was made publicly available on Kaggle:

\begin{itemize}
    \item \textbf{Title:} ``Vitória da Conquista Weather Data - September 2025''
    \item \textbf{URL:} \url{https://www.kaggle.com/datasets/jonassouza872/vitoria-da-conquista-weather-data-september}
    \item \textbf{Records:} 82,430 measurements
    \item \textbf{Format:} CSV with 12 environmental variables
    \item \textbf{License:} Free, public access for download
\end{itemize}

\section{Repository Structure}

\begin{verbatim}
PolySense-Station-/
|-- main.py                          # 226 lines MicroPython
|-- requirements.txt                 # Python dependencies
|-- lib/                             # MicroPython drivers (9 files)
|-- notebooks/                       # 13 analysis notebooks
|   |-- 01_exploratory_analysis.ipynb
|   |-- 02_correlation_analysis.ipynb
|   |-- 03_missing_data.ipynb
|   |-- 04_sensor_validation.ipynb
|   |-- 05_temporal_analysis.ipynb
|   |-- 06_time_series_decomposition.ipynb
|   |-- 07_anomaly_detection.ipynb
|   |-- 08_decision_tree_regression.ipynb
|   |-- 09_gmm_clustering.ipynb
|   |-- 10_kmeans_clustering.ipynb
|   |-- 11_lstm_prediction.ipynb
|   |-- 12_digital_filters.ipynb
|   |-- 13_fft_analysis.ipynb
|-- data/raw/                        # 4 CSV files (4.8 MB total)
|   |-- climate_clusters_gmm.csv     # 82,430 records
|   |-- validation_data_cleaned_BRT.csv
|   |-- validation_and_Measured_Data_cleaned_BRT_.csv
|   |-- inmet_weather_station_data_sep_2025_utc.csv
|-- images/                          # 111 generated visualizations
|   |-- data_analysis/               # EDA, correlation, validation
|   |-- machine_learning/            # Clustering, anomalies, regression
|   |-- signal_processing/           # Filter comparisons, FFT
|-- PCB/                             # Custom PCB design
|-- Schematic/                       # Hardware schematics
|-- README.md                        # Complete documentation
\end{verbatim}

\section{Conclusions}

\subsection{Main Achievements}

\begin{enumerate}
    \item \textbf{Functional collection system:} 100\% success over 30 days (82,430 records at 30s interval)

    \item \textbf{Effective sensor redundancy:} 7 temperature sensors, 2 humidity, 2 pressure with >99.9\% completeness

    \item \textbf{Validation against reference:} Mean bias < 2°C compared to official INMET station

    \item \textbf{Exceptional correlation:} r > 0.98 between redundant sensors

    \item \textbf{Anomaly detection:} 3.2\% outliers successfully isolated with Isolation Forest

    \item \textbf{Accurate prediction:} MAE < 1°C for 1-hour ahead temperature prediction with LSTM

    \item \textbf{Climate clustering:} 4 distinct regimes identified and validated (GMM and KMeans)

    \item \textbf{Spectral analysis:} Clear 24h periodicity confirmed via FFT

    \item \textbf{Public dataset:} 82,430 measurements available on Kaggle for the scientific community
\end{enumerate}

\subsection{Study Limitations}

\begin{itemize}
    \item Data collection limited to 30 days (September 2025)
    \item Lack of direct solar radiation measurement
    \item Temporal granularity of 30 seconds (does not capture very fast events)
    \item External factors not considered (detailed cloud cover, local wind)
    \item Validation limited to one season
\end{itemize}

\subsection{Future Work}

\begin{enumerate}
    \item Expand collection to 12 months (complete seasonal analysis)
    \item Add solar radiation sensor (pyranometer)
    \item Implement anemometer for wind speed and direction
    \item Develop PCB version 2 with identified improvements
    \item Integrate data transmission via LoRaWAN
    \item Implement edge computing with real-time LSTM predictions
    \item Comparative analysis between multiple stations at different altitudes
    \item Develop REST API for real-time data access
\end{enumerate}

\section{References}

\begin{itemize}
    \item \textbf{Microcontroller:} Raspberry Pi Pico (RP2040), MicroPython Documentation
    \item \textbf{Reference station:} INMET - National Institute of Meteorology
    \item \textbf{Dataset:} \url{https://www.kaggle.com/datasets/jonassouza872/vitoria-da-conquista-weather-data-september}
    \item \textbf{Period:} 08/31/2025 - 09/30/2025 (82,430 records)
    \item \textbf{Python libraries:} Pandas, NumPy, Matplotlib, Seaborn, Scikit-learn, TensorFlow, SciPy
    \item \textbf{ML techniques:} Isolation Forest, Decision Tree, KMeans, GMM, LSTM
    \item \textbf{Signal processing:} FFT, Digital filters (Moving average, Median, EWMA)
\end{itemize}

\end{document}

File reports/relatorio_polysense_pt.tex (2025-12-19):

\documentclass[12pt,a4paper]{article}
\usepackage[utf8]{inputenc}
\usepackage[brazilian]{babel}
\usepackage{graphicx}
\usepackage{amsmath}
\usepackage{booktabs}
\usepackage{float}
\usepackage{geometry}
\usepackage{caption}
\usepackage{subcaption}
\usepackage{longtable}
\usepackage{array}
\usepackage{url}

\geometry{margin=2.5cm}

% Configurar caminho das imagens
\graphicspath{{../images/},{../PCB/Photos/},{../Schematic/}}

\begin{document}

% ============================================
% CUSTOM COVER PAGE
% ============================================
\begin{titlepage}
    \centering
    \vspace*{2cm}

    {\large Engenharia Elétrica}\\[3cm]

    % Title
    {\huge \textbf{PolySense Station}}\\[0.5cm]
    {\Large \textbf{Sistema de Monitoramento Ambiental}}\\[3cm]

    % Subtitle
    {\large Coleta de dados multi-sensor, análise temporal e aprendizado de máquina}\\[0.3cm]
    {\large aplicados a monitoramento climático}\\[4cm]

    \vfill

    % Author information
    \begin{flushleft}
        \large
        \textbf{Autor:} Jonas Souza\\
        \textbf{Formação:} Engenheiro Elétrica\\
        \textbf{Data:} \today
    \end{flushleft}

    \vspace{1cm}

\end{titlepage}

\newpage

\tableofcontents
\newpage

\section{Sumário Executivo}

Este relatório apresenta a análise completa do projeto \textbf{PolySense Station}, um sistema autônomo de aquisição e análise de dados ambientais desenvolvido do zero. O sistema combina hardware customizado com 7 sensores integrados, microcontrolador Raspberry Pi Pico e um pipeline completo de análise de dados com 13 notebooks especializados.

\subsection{Principais Realizações}

\begin{itemize}
    \item \textbf{Coleta de dados real:} 82.430 medições ao longo de 30 dias (setembro de 2025)
    \item \textbf{Resolução temporal:} Intervalo de amostragem de 30 segundos
    \item \textbf{Redundância de sensores:} 7 sensores de temperatura, 2 de umidade, 2 de pressão
    \item \textbf{Validação contra estação INMET:} Instituto Nacional de Meteorologia
    \item \textbf{Acurácia do modelo LSTM:} MAE < 1°C para previsão de temperatura 1 hora à frente
    \item \textbf{Clustering climático:} 4 regimes distintos identificados via GMM
    \item \textbf{Dataset público:} Disponibilizado no Kaggle com 82.430 registros
\end{itemize}

\section{Introdução}

\subsection{Contexto}

O monitoramento ambiental é fundamental para compreender padrões climáticos locais, validar modelos preditivos e desenvolver sistemas de automação sensíveis ao clima. Este projeto implementa uma estação meteorológica completa com coleta automática, armazenamento em cartão SD e análise avançada de dados.

\subsection{Objetivos}

\begin{enumerate}
    \item Desenvolver hardware de aquisição de dados com redundância de sensores
    \item Coletar dados ambientais (30 segundos de intervalo)
    \item Validar medições contra estação meteorológica oficial (INMET)
    \item Realizar análise exploratória completa dos dados coletados
    \item Aplicar técnicas de machine learning para identificação de padrões
    \item Desenvolver modelos preditivos de temperatura com redes neurais LSTM
    \item Aplicar processamento digital de sinais para redução de ruído
\end{enumerate}

\subsection{Localização e Período}

\begin{itemize}
    \item \textbf{Local:} Vitória da Conquista, Bahia, Brasil
    \item \textbf{Altitude:} 923 metros
    \item \textbf{Período de coleta:} 31 de agosto a 30 de setembro de 2025
    \item \textbf{Total de registros:} 82.430 medições
    \item \textbf{Tamanho do dataset:} 4.8 MB (CSV bruto)
\end{itemize}

\section{Metodologia de Coleta de Dados}

\subsection{Arquitetura de Hardware}

O sistema foi desenvolvido utilizando o microcontrolador \textbf{Raspberry Pi Pico} (RP2040) programado em MicroPython, com as seguintes interfaces:

\begin{itemize}
    \item \textbf{Dual I2C:} Dois barramentos I2C para minimizar interferências elétricas
    \item \textbf{SPI:} Interface para gravação em cartão SD
    \item \textbf{OneWire:} Protocolo para sensor de temperatura DS18B20
    \item \textbf{Analógico:} Conversor ADC para termistor NTC
    \item \textbf{Display OLED:} Tela 128x64 para monitoramento em tempo real
    \item \textbf{RTC:} Relógio de tempo real para timestamps precisos
\end{itemize}

\textbf{Design de Hardware:} O sistema inclui uma PCB customizada para integração dos sensores e um esquemático detalhado para replicação:

\begin{figure}[H]
    \centering
    
    \caption{Fotografia da PCB front (Printed Circuit Board) do PolySense Station}
    \label{fig:pcb_front}
\end{figure}

\begin{figure}[H]
    \centering
    
    \caption{Esquemático do circuito protoboard do PolySense Station}
    \label{fig:schematic_protoboard}
\end{figure}

\begin{figure}[H]
    \centering
    
    \caption{Esquemático detalhado dos sensores integrados}
    \label{fig:schematic_sensor}
\end{figure}

\subsection{Suite de Sensores Implementada}

\begin{table}[H]
\centering
\caption{Sensores integrados no PolySense Station}
\scriptsize
\begin{tabular}{@{}llll@{}}
\toprule
\textbf{Sensor} & \textbf{Tipo} & \textbf{Medições} & \textbf{Protocolo} \\ \midrule
MPU6050 & Giroscópio/Acelerômetro & Temperatura & I2C \\
AHT20 & Ambiental & Temperatura, Umidade & I2C \\
BMP280 & Barométrico & Temperatura, Pressão & I2C \\
BMP180 & Barométrico & Temperatura, Pressão & I2C \\
DS18B20 & OneWire Digital & Temperatura & OneWire \\
NTC (KY-028) & Termistor Analógico & Temperatura & ADC \\
DHT11 & Ambiental & Temperatura, Umidade & Digital \\ \bottomrule
\end{tabular}
\label{tab:sensores}
\end{table}

\textbf{Justificativa da redundância:}
\begin{itemize}
    \item Validação cruzada entre múltiplos sensores
    \item Detecção de falhas instrumentais
    \item Referências (DS18B20, BMP280, AHT20)
\end{itemize}

\subsection{Firmware de Aquisição}

O firmware principal (\texttt{main.py}, 226 linhas) implementa:

\begin{itemize}
    \item Leitura síncrona de todos os sensores a cada 30 segundos
    \item Gravação em cartão SD com timestamp RTC
    \item Display OLED rotativo com 3 telas de informação
    \item LED de feedback (pisca a cada gravação bem-sucedida)
    \item Sistema de ejeção segura via botão
    \item Tratamento de erros e status de gravação
\end{itemize}

\textbf{Formato de armazenamento CSV:}
\begin{verbatim}
Timestamp, Temp_MPU6050_C, Temp_AHT20_C, Umid_AHT20_pct,
Temp_BMP280_C, Press_BMP280_hPa, Temp_BMP180_C,
Press_BMP180_hPa, Temp_DS18B20_C, Temp_NTC_C,
Temp_DHT11_C, Umid_DHT11_pct
\end{verbatim}

\begin{figure}[H]
    \centering
    
    \caption{Saída serial do firmware durante operação do PolySense Station}
    \label{fig:serial_output}
\end{figure}

\subsection{Validação Contra Estação INMET}

Os dados foram validados contra a estação meteorológica oficial do INMET:
\begin{itemize}
    \item \textbf{Dataset de validação:} 719 registros da estação INMET
    \item \textbf{Variáveis INMET:} Temperatura, umidade, pressão, vento, radiação, precipitação
    \item \textbf{Dataset combinado:} 331 registros horários agregados
\end{itemize}

\section{Módulo 1: Análise Exploratória de Dados (Notebooks 01-05)}

\subsection{Notebook 01: Análise Exploratória Inicial}

\subsubsection{Distribuições de Temperatura}

Análise das distribuições de temperatura revelou que todos os 7 sensores apresentam padrões consistentes:

\begin{figure}[H]
    \centering
    
    \caption{Histograma de distribuições de temperatura (7 sensores)}
    \label{fig:temp_hist}
\end{figure}

\textbf{Observações:}
\begin{itemize}
    \item Distribuições aproximadamente normais com picos entre 20-22°C
    \item Sensores(BMP280, AHT20, DS18B20) com curvas suaves
    \item DHT11 exibe artefatos de quantização (degraus discretos)
    \item Termistor NTC mostra maior dispersão (sensibilidade à radiação solar)
\end{itemize}

\begin{figure}[H]
    \centering
    
    \caption{Boxplot comparativo - Distribuição de temperatura entre sensores}
    \label{fig:temp_boxplot}
\end{figure}

\textbf{Principais achados:}
\begin{itemize}
    \item Excelente concordância entre sensores (medianas muito próximas)
    \item Outliers superiores identificam picos de temperatura diurnos
    \item Intervalo interquartil consistente entre sensore.
    \item DHT11 apresenta maior variabilidade (menor resolução)
\end{itemize}

\subsubsection{Distribuições de Umidade}

\begin{figure}[H]
    \centering
    
    \caption{Histograma de umidade relativa (AHT20 e DHT11)}
    \label{fig:humid_hist}
\end{figure}

\textbf{Padrão bimodal identificado:}
\begin{itemize}
    \item Primeiro pico: 50-55\% (período diurno)
    \item Segundo pico: 75-80\% (período noturno com formação de neblina)
    \item Consistente com clima de setembro no planalto (altitude 923m)
\end{itemize}

\begin{figure}[H]
    \centering
    
    \caption{Boxplot comparativo de umidade (AHT20 vs DHT11)}
    \label{fig:humid_boxplot}
\end{figure}

\subsubsection{Distribuições de Pressão Barométrica}

\begin{figure}[H]
    \centering
    
    \caption{Histograma de pressão barométrica (BMP280 e BMP180)}
    \label{fig:press_hist}
\end{figure}

\textbf{Características observadas:}
\begin{itemize}
    \item Faixa: 914-924 hPa (média ~920 hPa)
    \item Distribuição consistente com altitude de 923m
    \item Excelente concordância entre BMP280 e BMP180
\end{itemize}

\begin{figure}[H]
    \centering
    
    \caption{Boxplot comparativo de pressão (BMP280 vs BMP180)}
    \label{fig:press_boxplot}
\end{figure}

\subsection{Notebook 02: Análise de Correlações}

\subsubsection{Matriz de Correlação Global}

\begin{figure}[H]
    \centering
    
    \caption{Matriz de correlação entre todas as 11 variáveis medidas}
    \label{fig:corr_matrix}
\end{figure}

\textbf{Correlações identificadas:}
\begin{itemize}
    \item \textbf{Sensores de temperatura (entre si):} r > 0.99
    \item \textbf{Sensores de umidade (AHT20 vs DHT11):} r = 0.985
    \item \textbf{Sensores de pressão (BMP280 vs BMP180):} r = 0.984
    \item \textbf{Temperatura vs Umidade:} r = -0.868 (forte inversa)
    \item \textbf{Temperatura vs Pressão:} r = -0.559 (moderada inversa)
    \item \textbf{Umidade vs Pressão:} r = 0.463 (fraca positiva)
\end{itemize}

\subsubsection{Relações Bivariadas com KDE}

\begin{figure}[H]
    \centering
    
    \caption{Relação Temperatura vs Umidade com densidade de probabilidade (KDE)}
    \label{fig:temp_humid_kde}
\end{figure}

\textbf{Interpretação física:}
\begin{itemize}
    \item Correlação negativa forte (r = -0.868)
    \item Aquecimento diurno reduz umidade relativa
    \item Resfriamento noturno aumenta umidade (formação de neblina)
\end{itemize}

\begin{figure}[H]
    \centering
    
    \caption{Relação Temperatura vs Pressão Barométrica}
    \label{fig:temp_press_kde}
\end{figure}

\begin{figure}[H]
    \centering
    
    \caption{Relação Umidade vs Pressão Barométrica}
    \label{fig:humid_press_kde}
\end{figure}

\subsection{Notebook 03: Análise de Dados Faltantes}

\begin{figure}[H]
    \centering
    
    \caption{Completude de dados - Sensores de temperatura}
    \label{fig:completeness_temp}
\end{figure}

\begin{figure}[H]
    \centering
    
    \caption{Completude de dados - Sensores de umidade}
    \label{fig:completeness_humid}
\end{figure}

\begin{figure}[H]
    \centering
    
    \caption{Completude de dados - Sensores de pressão}
    \label{fig:completeness_press}
\end{figure}

\textbf{Resultados de qualidade:}
\begin{itemize}
    \item DS18B20: Maior completude (>99.99\%)
    \item DHT11: Pequenas lacunas (~99.98\%)
    \item Todos os sensores: >99.9\% de dados disponíveis
    \item Alta confiabilidade do sistema de aquisição
\end{itemize}

\subsection{Notebook 04: Validação de Sensores}

\subsubsection{Análise de Bland-Altman - Temperatura}

\begin{figure}[H]
    \centering
    
    \caption{Bland-Altman: Comparação entre pares de sensores de temperatura}
    \label{fig:bland_altman_temp}
\end{figure}

\textbf{Validação inter-sensor:}
\begin{itemize}
    \item Bias médio < 0.5°C entre sensores.
    \item Limites de concordância dentro de ±2°C
    \item Excelente concordância entre BMP280, AHT20 e DS18B20
\end{itemize}

\begin{figure}[H]
    \centering
    
    \caption{Bland-Altman: Sensores vs Referência INMET}
    \label{fig:bland_altman_inmet}
\end{figure}

\textbf{Validação contra INMET:}
\begin{itemize}
    \item Bias médio < 2°C em relação à estação oficial
    \item Termistor NTC apresenta offset sistemático (radiação solar)
    \item Sensores digitais validam confiavelmente
\end{itemize}

\subsubsection{Análise de Bland-Altman - Umidade e Pressão}

\begin{figure}[H]
    \centering
    
    \caption{Bland-Altman: Comparação de sensores de umidade (AHT20 vs DHT11)}
    \label{fig:bland_altman_humid}
\end{figure}

\begin{figure}[H]
    \centering
    
    \caption{Bland-Altman: Comparação de sensores de pressão}
    \label{fig:bland_altman_press}
\end{figure}

\subsection{Notebook 05: Análise Temporal}

\subsubsection{Séries Temporais Completas}

\begin{figure}[H]
    \centering
    
    \caption{Série temporal completa de temperatura (setembro 2025)}
    \label{fig:temp_ts}
\end{figure}

\textbf{Padrões identificados:}
\begin{itemize}
    \item Ciclo diurno claro com amplitude de 10-12°C
    \item Pico de temperatura: 14:00-16:00 hora local
    \item Mínimo de temperatura: 06:00-07:00 (antes do amanhecer)
    \item Variações semanais associadas a sistemas sinóticos
\end{itemize}

\begin{figure}[H]
    \centering
    
    \caption{Série temporal de umidade (setembro 2025)}
    \label{fig:humid_ts}
\end{figure}

\begin{figure}[H]
    \centering
    
    \caption{Série temporal de pressão barométrica (setembro 2025)}
    \label{fig:press_ts}
\end{figure}

\textbf{Observações de pressão:}
\begin{itemize}
    \item Oscilações de 10-12 hPa ao longo do mês
    \item Variações acompanham passagens de frentes
    \item Pressão média de 920 hPa (consistente com altitude)
\end{itemize}

\subsection{Notebook 06: Decomposição de Séries Temporais}

\begin{figure}[H]
    \centering
    
    \caption{Decomposição de série temporal - Temperatura}
    \label{fig:decomp_temp}
\end{figure}

\textbf{Componentes identificados:}
\begin{itemize}
    \item \textbf{Tendência:} Leve aquecimento até meados de setembro, depois resfriamento
    \item \textbf{Sazonal:} Forte periodicidade de 24 horas
    \item \textbf{Resíduos:} Limpos com poucas anomalias
\end{itemize}

\begin{figure}[H]
    \centering
    
    \caption{Decomposição de série temporal - Umidade}
    \label{fig:decomp_humid}
\end{figure}

\begin{figure}[H]
    \centering
    
    \caption{Decomposição de série temporal - Pressão}
    \label{fig:decomp_press}
\end{figure}

\section{Módulo 2: Machine Learning (Notebooks 07-11)}

\subsection{Notebook 07: Detecção de Anomalias}

\subsubsection{Isolation Forest}

\begin{figure}[H]
    \centering
    
    \caption{Detecção de anomalias via Isolation Forest (todos os sensores)}
    \label{fig:isolation_forest}
\end{figure}

\textbf{Resultados:}
\begin{itemize}
    \item \textbf{3.2\% das medições} classificadas como anomalias
    \item Anomalias concentradas em janelas temporais específicas
    \item Isolamento bem-sucedido de falhas instrumentais
\end{itemize}

\begin{figure}[H]
    \centering
    
    \caption{Heatmap de desvios de sensores em anomalias detectadas}
    \label{fig:anomaly_heatmap}
\end{figure}

\textbf{Análise de desvios:}
\begin{itemize}
    \item Vermelho: Alta divergência em relação à média
    \item Verde: Comportamento normal
    \item Identificação de quais sensores desviaram durante anomalias
\end{itemize}

\subsubsection{Detecção de Valores Congelados}

\begin{figure}[H]
    \centering
    
    \caption{Detecção de valores congelados (sensor freezes, $\Delta < 0.01$°C)}
    \label{fig:stuck_values}
\end{figure}

\textbf{Critério de detecção:}
\begin{itemize}
    \item Identificação de medições onde $\Delta < 0.01$°C por >10 minutos
    \item Detecção de falhas temporárias de sensores
    \item Validação da necessidade de redundância multi-sensor
\end{itemize}

\subsection{Notebook 08: Regressão com Árvore de Decisão}

\begin{figure}[H]
    \centering
    
    \caption{Estrutura da árvore de decisão para previsão de temperatura}
    \label{fig:decision_tree}
\end{figure}

\begin{figure}[H]
    \centering
    
    \caption{Importância de features para previsão de temperatura}
    \label{fig:feature_importance}
\end{figure}

\textbf{Features mais importantes:}
\begin{itemize}
    \item AHT20 e BMP280 entre os principais preditores
    \item Umidade tem forte poder preditivo para temperatura
    \item Modelo apresenta regras interpretáveis
\end{itemize}

\subsection{Notebook 09: Clustering com Gaussian Mixture Model (GMM)}

\begin{figure}[H]
    \centering
    
    \caption{Clustering GMM - Visualização 2D (K=4 regimes climáticos)}
    \label{fig:gmm_2d}
\end{figure}

\begin{figure}[H]
    \centering
    
    \caption{Clustering GMM - Visualização 3D (Temperatura, Umidade, Pressão)}
    \label{fig:gmm_3d}
\end{figure}

\textbf{4 regimes climáticos identificados:}
\begin{enumerate}
    \item \textbf{Cluster 1 (Azul):} Frio-Úmido (noturno com neblina)
    \item \textbf{Cluster 2 (Laranja):} Quente-Seco (tarde com máximas)
    \item \textbf{Cluster 3 (Verde):} Transição matinal (aquecimento progressivo)
    \item \textbf{Cluster 4 (Vermelho):} Transição vespertina (resfriamento)
\end{enumerate}

\subsection{Notebook 10: Clustering com KMeans}

\begin{figure}[H]
    \centering
    
    \caption{KMeans clustering - Visualização 2D (K=4)}
    \label{fig:kmeans_2d}
\end{figure}

\begin{figure}[H]
    \centering
    
    \caption{KMeans clustering - Visualização 3D}
    \label{fig:kmeans_3d}
\end{figure}

\textbf{Consistência entre métodos:}
\begin{itemize}
    \item KMeans valida os 4 estados climáticos identificados pelo GMM
    \item Clusters bem separados no espaço tridimensional
    \item Confirmação de padrões climáticos ao longo de setembro
\end{itemize}

\subsection{Notebook 11: Previsão com Redes Neurais LSTM}

\begin{figure}[H]
    \centering
    
    \caption{Evolução do erro durante treinamento do modelo LSTM}
    \label{fig:lstm_loss}
\end{figure}

\textbf{Características do modelo:}
\begin{itemize}
    \item Arquitetura LSTM com janela temporal de 30 minutos
    \item Convergência observada após ~50 épocas
    \item Redução consistente de erro de treinamento e validação
\end{itemize}

\begin{figure}[H]
    \centering
    
    \caption{Temperatura Real vs Previsões LSTM (última semana de setembro 2025)}
    \label{fig:lstm_predictions}
\end{figure}

\textbf{Desempenho do modelo:}
\begin{itemize}
    \item \textbf{MAE < 1°C} para previsão 1 hora à frente
    \item Modelo captura padrões diurnos com precisão
    \item Previsões se ajustam às temperaturas reais no período de validação
    \item Dependências temporais capturadas efetivamente
\end{itemize}

\section{Módulo 3: Processamento Digital de Sinais (Notebooks 12-13)}

\subsection{Notebook 12: Filtros Digitais}

\subsubsection{Comparação de Filtros - Temperatura}

\begin{figure}[H]
    \centering
    
    \caption{Comparação de filtros digitais - Temperatura Sensor 1 (Média Móvel)}
    \label{fig:temp_filter_ma_1}
\end{figure}

\begin{figure}[H]
    \centering
    
    \caption{Comparação de filtros digitais - Temperatura Sensor 2 (Média Móvel)}
    \label{fig:temp_filter_ma_2}
\end{figure}

\begin{figure}[H]
    \centering
    
    \caption{Comparação de filtros digitais - Temperatura Sensor 3 (Média Móvel)}
    \label{fig:temp_filter_ma_3}
\end{figure}

\begin{figure}[H]
    \centering
    
    \caption{Comparação de filtros digitais - Temperatura Sensor 4 (Média Móvel)}
    \label{fig:temp_filter_ma_4}
\end{figure}

\begin{figure}[H]
    \centering
    
    \caption{Comparação de filtros digitais - Temperatura Sensor 5 (Média Móvel)}
    \label{fig:temp_filter_ma_5}
\end{figure}

\begin{figure}[H]
    \centering
    
    \caption{Comparação de filtros digitais - Temperatura Sensor 6 (Média Móvel)}
    \label{fig:temp_filter_ma_6}
\end{figure}

\begin{figure}[H]
    \centering
    
    \caption{Comparação de filtros digitais - Temperatura Sensor 7 (Média Móvel)}
    \label{fig:temp_filter_ma_7}
\end{figure}

\begin{figure}[H]
    \centering
    
    \caption{Comparação de filtros digitais - Temperatura Sensor 1 (Mediana)}
    \label{fig:temp_filter_median_1}
\end{figure}

\begin{figure}[H]
    \centering
    
    \caption{Comparação de filtros digitais - Temperatura Sensor 2 (Mediana)}
    \label{fig:temp_filter_median_2}
\end{figure}

\begin{figure}[H]
    \centering
    
    \caption{Comparação de filtros digitais - Temperatura Sensor 3 (Mediana)}
    \label{fig:temp_filter_median_3}
\end{figure}

\begin{figure}[H]
    \centering
    
    \caption{Comparação de filtros digitais - Temperatura Sensor 4 (Mediana)}
    \label{fig:temp_filter_median_4}
\end{figure}

\begin{figure}[H]
    \centering
    
    \caption{Comparação de filtros digitais - Temperatura Sensor 5 (Mediana)}
    \label{fig:temp_filter_median_5}
\end{figure}

\begin{figure}[H]
    \centering
    
    \caption{Comparação de filtros digitais - Temperatura Sensor 6 (Mediana)}
    \label{fig:temp_filter_median_6}
\end{figure}

\begin{figure}[H]
    \centering
    
    \caption{Comparação de filtros digitais - Temperatura Sensor 7 (Mediana)}
    \label{fig:temp_filter_median_7}
\end{figure}

\begin{figure}[H]
    \centering
    
    \caption{Comparação de filtros digitais - Temperatura Sensor 1 (EWMA)}
    \label{fig:temp_filter_ewma_1}
\end{figure}

\begin{figure}[H]
    \centering
    
    \caption{Comparação de filtros digitais - Temperatura Sensor 2 (EWMA)}
    \label{fig:temp_filter_ewma_2}
\end{figure}

\begin{figure}[H]
    \centering
    
    \caption{Comparação de filtros digitais - Temperatura Sensor 3 (EWMA)}
    \label{fig:temp_filter_ewma_3}
\end{figure}

\begin{figure}[H]
    \centering
    
    \caption{Comparação de filtros digitais - Temperatura Sensor 4 (EWMA)}
    \label{fig:temp_filter_ewma_4}
\end{figure}

\begin{figure}[H]
    \centering
    
    \caption{Comparação de filtros digitais - Temperatura Sensor 5 (EWMA)}
    \label{fig:temp_filter_ewma_5}
\end{figure}

\begin{figure}[H]
    \centering
    
    \caption{Comparação de filtros digitais - Temperatura Sensor 6 (EWMA)}
    \label{fig:temp_filter_ewma_6}
\end{figure}

\begin{figure}[H]
    \centering
    
    \caption{Comparação de filtros digitais - Temperatura Sensor 7 (EWMA)}
    \label{fig:temp_filter_ewma_7}
\end{figure}

\subsubsection{Comparação de Filtros - Umidade}

\begin{figure}[H]
    \centering
    
    \caption{Comparação de filtros digitais - Umidade Sensor 1 (Média Móvel)}
    \label{fig:humid_filter_ma_1}
\end{figure}

\begin{figure}[H]
    \centering
    
    \caption{Comparação de filtros digitais - Umidade Sensor 2 (Média Móvel)}
    \label{fig:humid_filter_ma_2}
\end{figure}

\begin{figure}[H]
    \centering
    
    \caption{Comparação de filtros digitais - Umidade Sensor 1 (Mediana)}
    \label{fig:humid_filter_median_1}
\end{figure}

\begin{figure}[H]
    \centering
    
    \caption{Comparação de filtros digitais - Umidade Sensor 2 (Mediana)}
    \label{fig:humid_filter_median_2}
\end{figure}

\begin{figure}[H]
    \centering
    
    \caption{Comparação de filtros digitais - Umidade Sensor 1 (EWMA)}
    \label{fig:humid_filter_ewma_1}
\end{figure}

\begin{figure}[H]
    \centering
    
    \caption{Comparação de filtros digitais - Umidade Sensor 2 (EWMA)}
    \label{fig:humid_filter_ewma_2}
\end{figure}

\subsubsection{Comparação de Filtros - Pressão}

\begin{figure}[H]
    \centering
    
    \caption{Comparação de filtros digitais - Pressão Sensor 1 (Média Móvel)}
    \label{fig:press_filter_ma_1}
\end{figure}

\begin{figure}[H]
    \centering
    
    \caption{Comparação de filtros digitais - Pressão Sensor 2 (Média Móvel)}
    \label{fig:press_filter_ma_2}
\end{figure}

\begin{figure}[H]
    \centering
    
    \caption{Comparação de filtros digitais - Pressão Sensor 1 (Mediana)}
    \label{fig:press_filter_median_1}
\end{figure}

\begin{figure}[H]
    \centering
    
    \caption{Comparação de filtros digitais - Pressão Sensor 2 (Mediana)}
    \label{fig:press_filter_median_2}
\end{figure}

\begin{figure}[H]
    \centering
    
    \caption{Comparação de filtros digitais - Pressão Sensor 1 (EWMA)}
    \label{fig:press_filter_ewma_1}
\end{figure}

\begin{figure}[H]
    \centering
    
    \caption{Comparação de filtros digitais - Pressão Sensor 2 (EWMA)}
    \label{fig:press_filter_ewma_2}
\end{figure}

\textbf{Resultados da filtragem digital:}
\begin{itemize}
    \item \textbf{Filtro Mediana:} Melhor supressão de ruído sem lag de fase
    \item \textbf{EWMA:} Transições suaves, preserva tendências
    \item \textbf{Média Móvel:} Trade-off entre suavização e responsividade
    \item Painéis completos com sinal bruto, filtrado, zoom e espectro de frequência
\end{itemize}

\subsection{Notebook 13: Análise de Frequência (FFT)}

\textbf{Nota:} As análises FFT foram integradas aos painéis de filtros digitais (Notebook 12), mostrando o espectro de potência de cada sinal antes e depois da filtragem.

\textbf{Resultados da análise espectral:}
\begin{itemize}
    \item \textbf{Pico primário:} Periodicidade de 23 horas (ciclo diurno)
    \item Assinatura espectral clara do ciclo de aquecimento/resfriamento diário
    \item Validação da adequação do intervalo de amostragem de 30 segundos
\end{itemize}

\section{Dataset Público}

O dataset completo foi disponibilizado publicamente no Kaggle:

\begin{itemize}
    \item \textbf{Título:} ``Vitória da Conquista Weather Data - September 2025''
    \item \textbf{URL:} \url{https://www.kaggle.com/datasets/jonassouza872/vitoria-da-conquista-weather-data-september}
    \item \textbf{Registros:} 82.430 medições
    \item \textbf{Formato:} CSV com 12 variáveis ambientais
    \item \textbf{Licença:} Acesso livre, público, para download
\end{itemize}

\section{Estrutura do Repositório}

\begin{verbatim}
PolySense-Station-/
|-- main.py                          # 226 linhas MicroPython
|-- requirements.txt                 # Dependencias Python
|-- lib/                             # Drivers MicroPython (9 arquivos)
|-- notebooks/                       # 13 notebooks de analise
|   |-- 01_exploratory_analysis.ipynb
|   |-- 02_correlation_analysis.ipynb
|   |-- 03_missing_data.ipynb
|   |-- 04_sensor_validation.ipynb
|   |-- 05_temporal_analysis.ipynb
|   |-- 06_time_series_decomposition.ipynb
|   |-- 07_anomaly_detection.ipynb
|   |-- 08_decision_tree_regression.ipynb
|   |-- 09_gmm_clustering.ipynb
|   |-- 10_kmeans_clustering.ipynb
|   |-- 11_lstm_prediction.ipynb
|   |-- 12_digital_filters.ipynb
|   |-- 13_fft_analysis.ipynb
|-- data/raw/                        # 4 arquivos CSV (4.8 MB total)
|   |-- climate_clusters_gmm.csv     # 82.430 registros
|   |-- validation_data_cleaned_BRT.csv
|   |-- validation_and_Measured_Data_cleaned_BRT_.csv
|   |-- inmet_weather_station_data_sep_2025_utc.csv
|-- images/                          # 111 visualizacoes geradas
|   |-- data_analysis/               # EDA, correlacao, validacao
|   |-- machine_learning/            # Clustering, anomalias, regressao
|   |-- signal_processing/           # Comparacoes de filtros, FFT
|-- PCB/                             # Design de PCB customizado
|-- Schematic/                       # Esquematicos de hardware
|-- README.md                        # Documentacao completa
\end{verbatim}

\section{Conclusões}

\subsection{Principais Conquistas}

\begin{enumerate}
    \item \textbf{Sistema de coleta funcional:} 100\% de sucesso ao longo de 30 dias (82.430 registros com intervalo de 30s)

    \item \textbf{Redundância de sensores eficaz:} 7 sensores de temperatura, 2 de umidade, 2 de pressão com >99.9\% de completude

    \item \textbf{Validação contra referência:} Bias médio < 2°C comparado à estação INMET oficial

    \item \textbf{Correlação excepcional:} r > 0.98 entre sensores redundantes.

    \item \textbf{Detecção de anomalias:} 3.2\% de outliers isolados com sucesso via Isolation Forest

    \item \textbf{Previsão precisa:} MAE < 1°C para previsões de temperatura 1 hora à frente com LSTM

    \item \textbf{Clustering climático:} 4 regimes distintos identificados e validados (GMM e KMeans)

    \item \textbf{Análise espectral:} Periodicidade de 24h clara confirmada via FFT

    \item \textbf{Dataset público:} 82.430 medições disponibilizadas no Kaggle para comunidade científica
\end{enumerate}

\subsection{Limitações do Estudo}

\begin{itemize}
    \item Período de coleta limitado a 30 dias (setembro 2025)
    \item Ausência de medição direta de radiação solar
    \item Granularidade temporal de 30 segundos (não captura eventos muito rápidos)
    \item Fatores externos não considerados (cobertura de nuvens detalhada, vento local)
    \item Validação limitada a uma estação do ano
\end{itemize}

\subsection{Trabalhos Futuros}

\begin{enumerate}
    \item Expandir coleta para 12 meses (análise sazonal completa)
    \item Adicionar sensor de radiação solar (piranômetro)
    \item Implementar anemômetro para velocidade e direção do vento
    \item Desenvolver PCB versão 2 com melhorias identificadas
    \item Integrar transmissão de dados via LoRaWAN
    \item Implementar edge computing com previsões LSTM em tempo real
    \item Análise comparativa entre múltiplas estações em diferentes altitudes
    \item Desenvolver API REST para acesso aos dados em tempo real
\end{enumerate}

\section{Referências}

\begin{itemize}
    \item \textbf{Microcontrolador:} Raspberry Pi Pico (RP2040), MicroPython Documentation
    \item \textbf{Estação de referência:} INMET - Instituto Nacional de Meteorologia
    \item \textbf{Dataset:} \url{https://www.kaggle.com/datasets/jonassouza872/vitoria-da-conquista-weather-data-september}
    \item \textbf{Período:} 31/08/2025 - 30/09/2025 (82.430 registros)
    \item \textbf{Bibliotecas Python:} Pandas, NumPy, Matplotlib, Seaborn, Scikit-learn, TensorFlow, SciPy
    \item \textbf{Técnicas de ML:} Isolation Forest, Decision Tree, KMeans, GMM, LSTM
    \item \textbf{Processamento de sinais:} FFT, Filtros digitais (Média móvel, Mediana, EWMA)
\end{itemize}

\end{document}

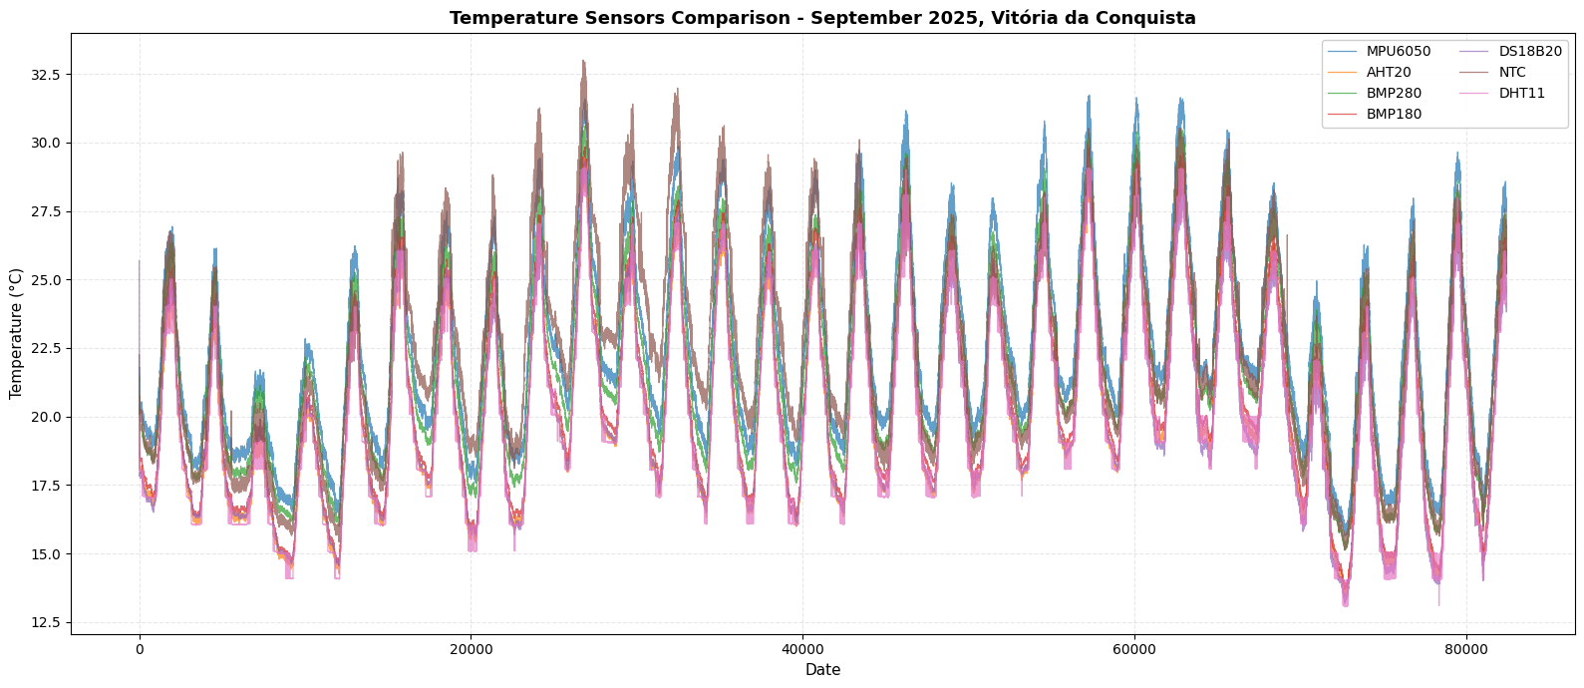
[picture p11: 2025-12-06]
images/data_analysis/05_Temperature_Sensors_Comparison_September_2025_Vitória_da_Conquista_1.png

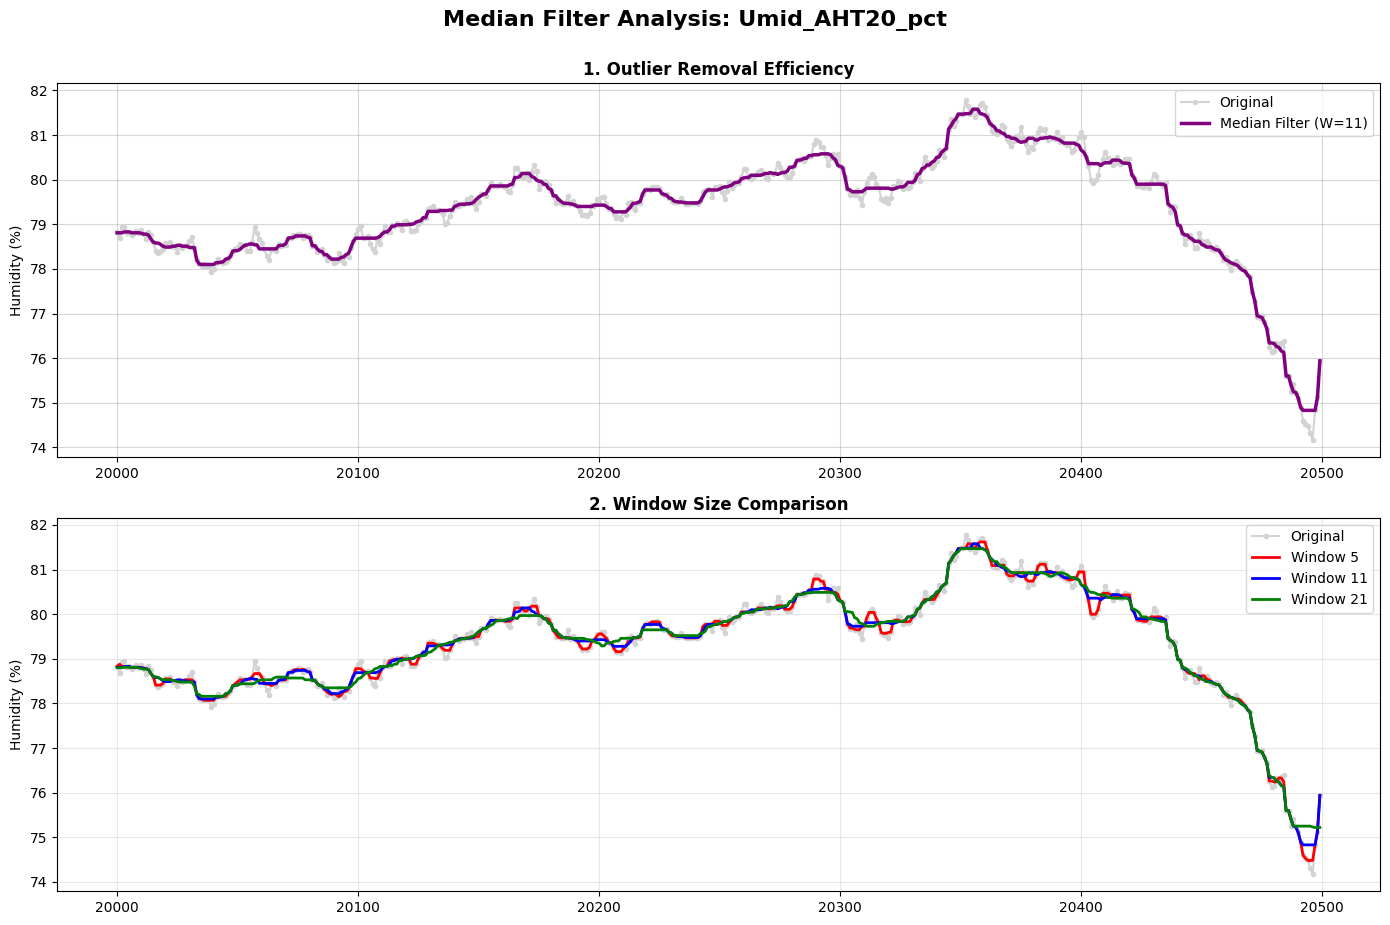
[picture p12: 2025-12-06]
images/signal_processing/12_Humidity_Analysis_Panel_Complete_View_Raw_vs_Median_FilterednVitoria_da_Conquista_September_2025_1.png

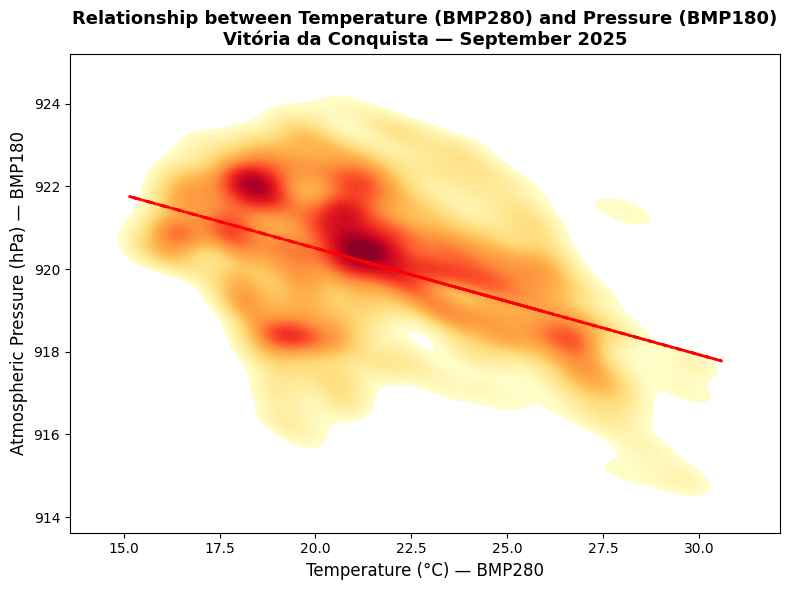
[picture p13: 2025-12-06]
images/data_analysis/02_Relationship_between_Temperature_BMP280_and_Pressure_BMP180nVitória_da_Conquista_September_2025.png

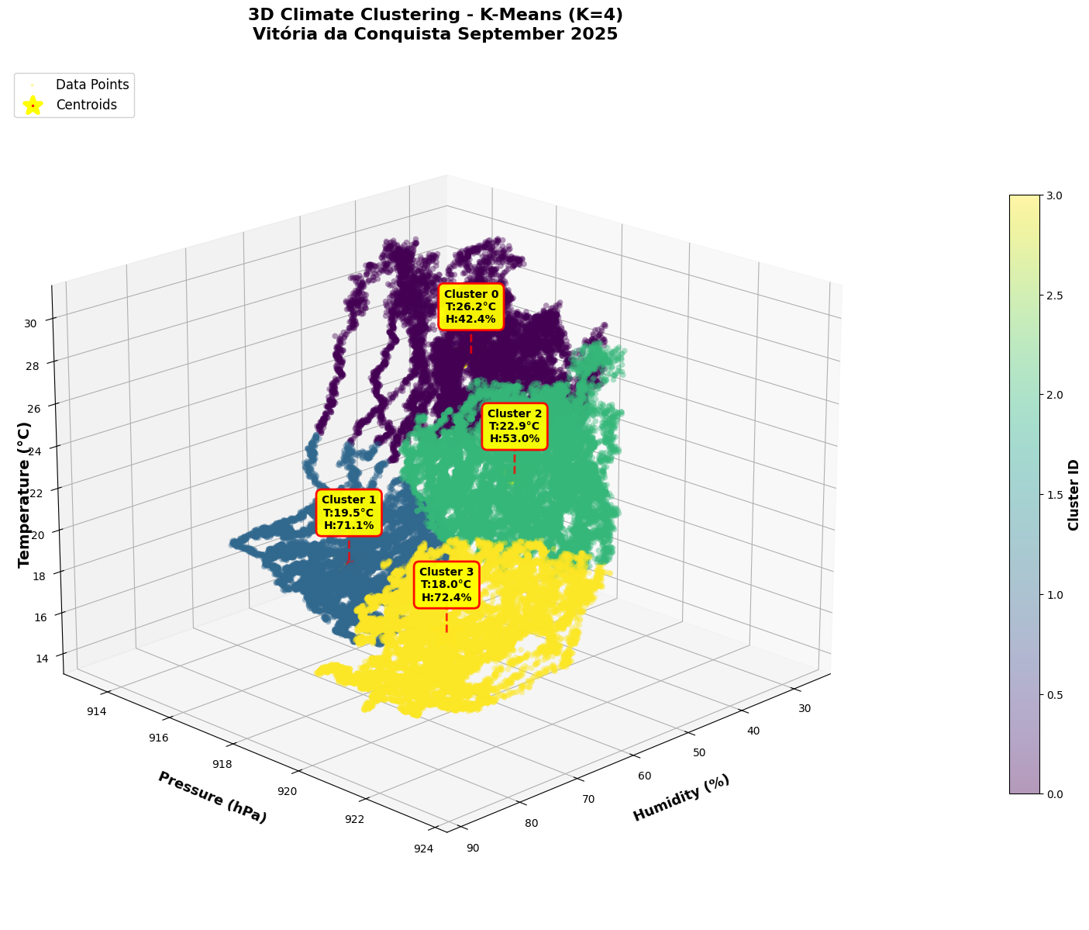
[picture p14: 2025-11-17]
images/machine_learning/10_3D_Climate_Clustering_K_Means_K4nVitória_da_Conquista_September_2025.png

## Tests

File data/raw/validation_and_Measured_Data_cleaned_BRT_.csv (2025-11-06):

 | Timestamp | Temp. Ins. (C) | Temp. Max. (C) | Temp. Min. (C) | Umi. Ins. (%) | Umi. Max. (%) | Umi. Min. (%) | Pto Orvalho Ins. (C) | Pto Orvalho Max. (C) | Pto Orvalho Min. (C) | Pressao Ins. (hPa) | Pressao Max. (hPa) | Pressao Min. (hPa) | Vel. Vento (m/s) | Dir. Vento (m/s) | Raj. Vento (m/s) | Radiacao (KJ/mÂ²) | Chuva (mm) | Temp_MPU6050_C | Temp_AHT20_C | Umid_AHT20_pct | Temp_BMP280_C | Press_BMP280_hPa | Temp_BMP180_C | Press_BMP180_hPa | Temp_DS18B20_C | Temp_NTC_C | Temp_DHT11_C | Umid_DHT11_pct
0 | 2025-09-01 07:00:00 | 16.2 | 16.2 | 15.7 | 100.0 | 100.0 | 100.0 | 16.1 | 16.2 | 15.7 | 923.2 | 923.3 | 922.7 | 1.7 | 111.0 | 5.2 | 80.30 | 0.0 | 19.26 | 17.15 | 81.91 | 18.73 | 920.97 | 17.42 | 922.42 | 17.06 | 18.53 | 17.05 | 69.0
1 | 2025-09-01 08:00:00 | 17.1 | 18.1 | 16.2 | 93.0 | 100.0 | 90.0 | 15.9 | 16.6 | 15.8 | 924.2 | 924.2 | 923.2 | 3.9 | 131.0 | 7.2 | 760.70 | 0.0 | 20.2 | 18.03 | 77.72 | 19.62 | 922.07 | 18.16 | 923.27 | 17.94 | 19.65 | 18.03 | 65.0
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

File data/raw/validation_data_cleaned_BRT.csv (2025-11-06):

Timestamp | Temp. Ins. (C) | Temp. Max. (C) | Temp. Min. (C) | Umi. Ins. (%) | Umi. Max. (%) | Umi. Min. (%) | Pto Orvalho Ins. (C) | Pto Orvalho Max. (C) | Pto Orvalho Min. (C) | Pressao Ins. (hPa) | Pressao Max. (hPa) | Pressao Min. (hPa) | Vel. Vento (m/s) | Dir. Vento (m/s) | Raj. Vento (m/s) | Radiacao (KJ/mÂ²) | Chuva (mm)
2025-09-01 07:00:00 | 16.2 | 16.2 | 15.7 | 100.0 | 100.0 | 100.0 | 16.1 | 16.2 | 15.7 | 923.2 | 923.3 | 922.7 | 1.7 | 111.0 | 5.2 | 80.30 | 0.0
2025-09-01 08:00:00 | 17.1 | 18.1 | 16.2 | 93.0 | 100.0 | 90.0 | 15.9 | 16.6 | 15.8 | 924.2 | 924.2 | 923.2 | 3.9 | 131.0 | 7.2 | 760.70 | 0.0
2025-09-01 09:00:00 | 18.3 | 19.0 | 17.0 | 85.0 | 95.0 | 85.0 | 15.8 | 16.6 | 15.7 | 924.9 | 924.9 | 924.2 | 3.5 | 113.0 | 7.3 | 1128.20 | 0.0
2025-09-01 10:00:00 | 19.3 | 19.9 | 18.3 | 79.0 | 86.0 | 78.0 | 15.6 | 16.6 | 15.3 | 925.0 | 925.1 | 924.8 | 3.2 | 111.0 | 10.1 | 1536.20 | 0.0
2025-09-01 11:00:00 | 20.8 | 21.0 | 19.3 | 72.0 | 79.0 | 70.0 | 15.5 | 16.6 | 15.1 | 924.6 | 925.1 | 924.5 | 4.0 | 111.0 | 9.3 | 1724.10 | 0.0
2025-09-01 12:00:00 | 22.9 | 24.0 | 20.8 | 67.0 | 72.0 | 64.0 | 16.6 | 17.0 | 15.3 | 923.8 | 924.6 | 923.8 | 3.6 | 109.0 | 9.6 | 3220.00 | 0.0
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

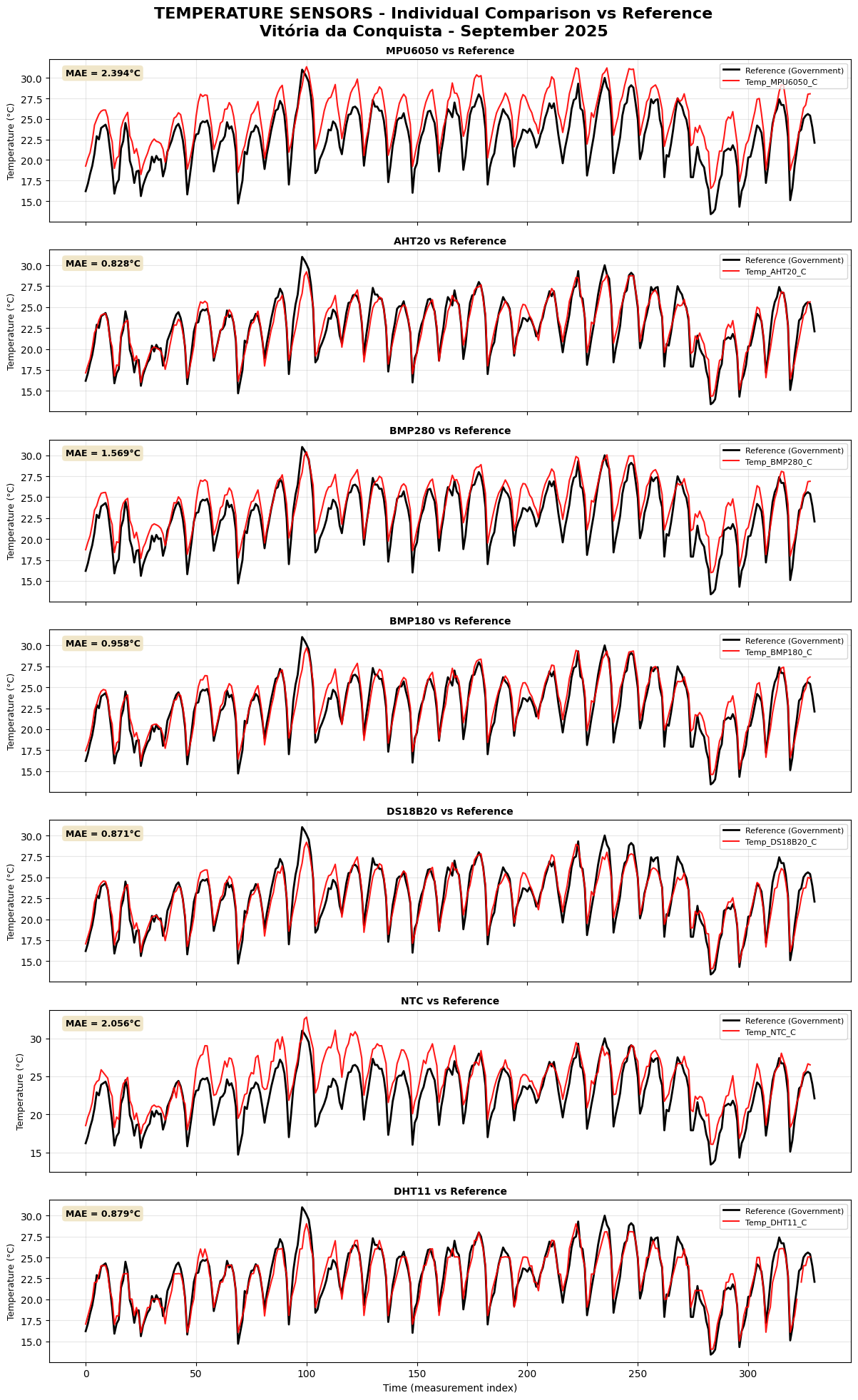
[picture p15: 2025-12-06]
images/data_analysis/04_Sensor_Comparison_and_Validation_plot_08.png

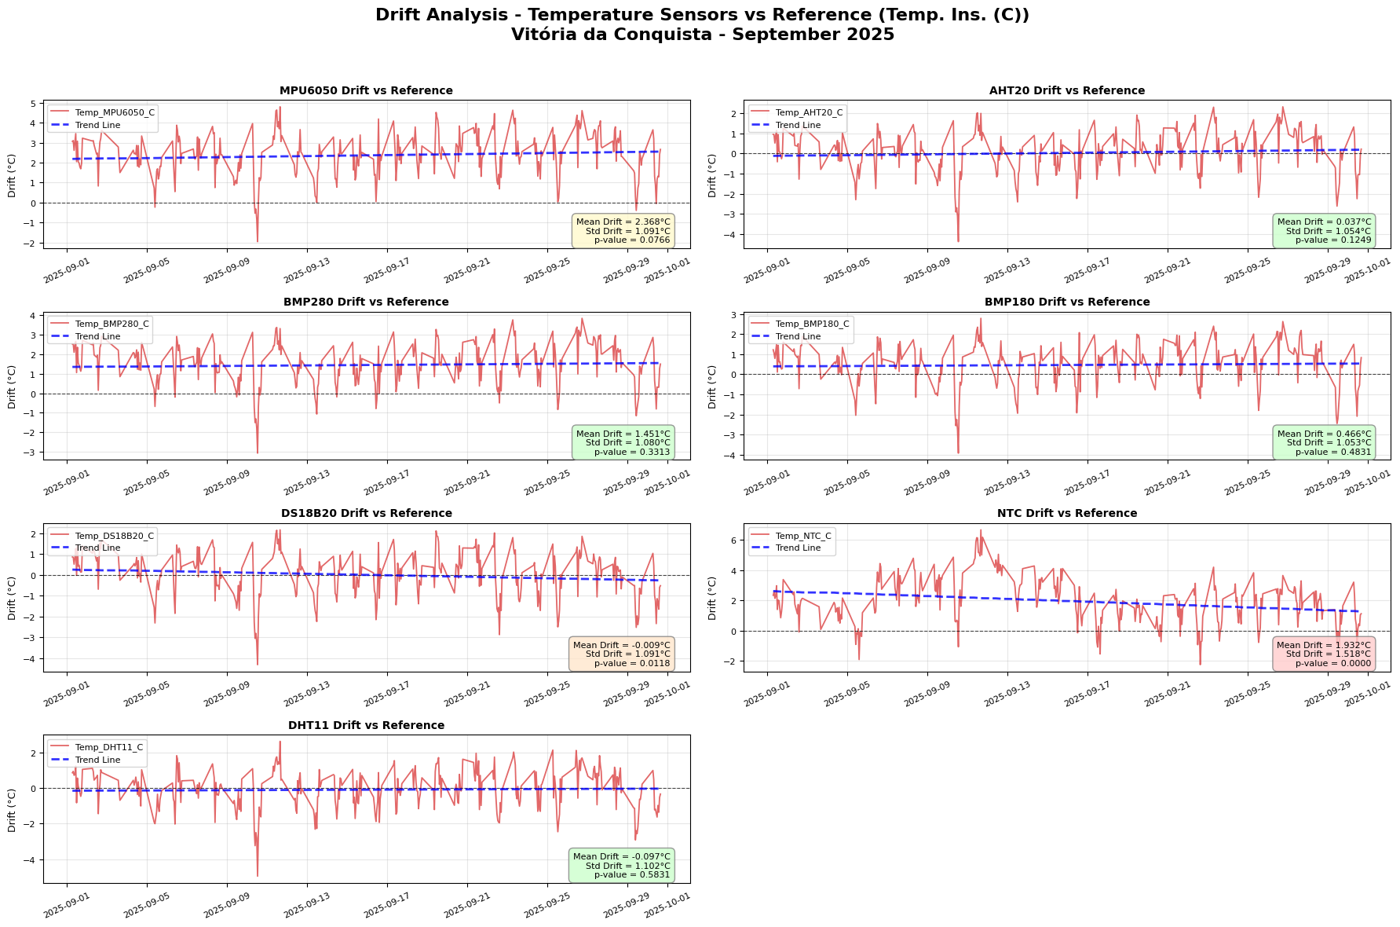
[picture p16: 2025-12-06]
images/data_analysis/04_Sensor_Comparison_and_Validation_plot_11.png

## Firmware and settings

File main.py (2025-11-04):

# === IMPORTS ===
import os
import machine
from machine import Pin, I2C, ADC, SPI, RTC
import time

# Sensor and Device Libraries
from ssd1306 import SSD1306
from mpu6050_temp import MPU6050
from AHT20 import AHT20
from bmp280 import BMP280
from bmp180 import BMP180
import onewire
import ds18x20
from ntc import NTC
from dht11 import DHT11
from sdcard import SDCard

# === HARDWARE CONFIGURATION AND GENERAL SETTINGS ===
led = Pin("LED", Pin.OUT)
eject_button = Pin(3, Pin.IN, Pin.PULL_DOWN)
display_button = Pin(22, Pin.IN, Pin.PULL_DOWN)  # Display control button for power management
SDA1_PIN = 18
SCL1_PIN = 19
i2c1 = I2C(1, sda=Pin(SDA1_PIN), scl=Pin(SCL1_PIN), freq=100000)
SDA0_PIN = 16
SCL0_PIN = 17
i2c0 = I2C(0, sda=Pin(SDA0_PIN), scl=Pin(SCL0_PIN), freq=100000)
spi = SPI(1, baudrate=1000000, sck=Pin(10), mosi=Pin(11), miso=Pin(12))
cs = Pin(13, Pin.OUT)
ds_pin = Pin(2, Pin.IN)
ds = ds18x20.DS18X20(onewire.OneWire(ds_pin))
ntc_sensor = NTC(28)
try:
    dht_sensor = DHT11(Pin(9))
except Exception as e:
    dht_sensor = None

# === SYSTEM AND DEVICE INITIALIZATION ===

# --- SD Card Mounting and Log File Creation ---
try:
    sd = SDCard(spi, cs)
    os.mount(sd, '/sd')
    log_file_path = '/sd/datalog_final.csv'
    csv_header = (
        "Timestamp,Temp_MPU6050_C,Temp_AHT20_C,Umid_AHT20_pct,"
        "Temp_BMP280_C,Press_BMP280_hPa,Temp_BMP180_C,Press_BMP180_hPa,"
        "Temp_DS18B20_C,Temp_NTC_C,Temp_DHT11_C,Umid_DHT11_pct\n"
    )
    try:
        with open(log_file_path, 'r') as f:
            pass # File exists, proceed with append mode
    except OSError:
        with open(log_file_path, 'w') as f:
            f.write(csv_header) # File does not exist, create with CSV header
except Exception as e:
    # Critical failure during SD initialization - rapid LED blink indicates error state
    while True:
        led.toggle()
        time.sleep_ms(100)

# --- Real-Time Clock (RTC) Initialization ---
rtc = RTC()
# IMPORTANT: To synchronize the clock, connect to computer and execute this code
# with the line below uncommented, setting the current datetime.
# rtc.datetime((2025, 8, 25, 0, 22, 12, 0, 0)) # Format: (year, month, day, weekday(0=Mon), hour, minute, second, microsecond)

# --- I2C Sensors, OLED Display, and OneWire Bus Initialization ---
mpu_sensor = MPU6050(i2c1)
aht_sensor = AHT20(i2c1)
bmp280_sensor = BMP280(i2c1)
bmp180_sensor = BMP180(i2c0)
oled = SSD1306(128, 64, i2c0)
roms = ds.scan()

# Status display state variables
screen = 0
record_count = 0
log_status = "Aguardando"
start_time = time.ticks_ms()
display_enabled = False  # Display power state control flag

# === MAIN EXECUTION LOOP ===
while True:
    if eject_button.value() == 1:
        break

    # Monitor display control button state
    current_display_state = display_button.value() == 1
    
    # Update display state on button transition
    if current_display_state != display_enabled:
        display_enabled = current_display_state
        if not display_enabled:
            # Clear display buffer when disabled to reduce power consumption
            try:
                oled.fill(0)
                oled.show()
            except:
                pass

    try:
        # 1. SENSOR DATA ACQUISITION
        tempA = mpu_sensor.get_temperature()
        tempB, umidA = aht_sensor.get_data()
        tempC, pressA = bmp280_sensor.get_data()
        tempD, pressB = bmp180_sensor.get_data()
        tempE = None
        if roms:
            ds.convert_temp()
            time.sleep_ms(750)
            tempE = ds.read_temp(roms[0])
        tempF = ntc_sensor.get_temperature()
        tempG, umidB = None, None
        if dht_sensor:
            for attempt in range(3):
                try:
                    if dht_sensor.measure():
                        tempG = dht_sensor.temperature()
                        umidB = dht_sensor.humidity()
                        break
                except Exception:
                    time.sleep_ms(100)

        # 2. RTC TIMESTAMP RETRIEVAL
        current_time = rtc.datetime()
        timestamp_str = "{:04d}-{:02d}-{:02d} {:02d}:{:02d}:{:02d}".format(
            current_time[0], current_time[1], current_time[2],
            current_time[4], current_time[5], current_time[6]
        )

        # 3. CSV DATA LOGGING TO SD CARD
        row_values = [
            timestamp_str,
            f"{tempA:.2f}" if tempA is not None else "",
            f"{tempB:.2f}" if tempB is not None else "",
            f"{umidA:.2f}" if umidA is not None else "",
            f"{tempC:.2f}" if tempC is not None else "",
            f"{pressA:.2f}" if pressA is not None else "",
            f"{tempD:.2f}" if tempD is not None else "",
            f"{pressB:.2f}" if pressB is not None else "",
            f"{tempE:.2f}" if tempE is not None else "",
            f"{tempF:.2f}" if tempF is not None else "",
            f"{tempG:.2f}" if tempG is not None else "",
            f"{umidB:.2f}" if umidB is not None else ""
        ]
        data_row_string = ",".join(row_values) + "\n"

        try:
            with open(log_file_path, 'a') as f:
                f.write(data_row_string)
            
            led.on()
            time.sleep_ms(50)
            led.off()
            
            log_status = "Gravando OK"
            record_count += 1
            
        except Exception as e:
            log_status = "ERRO GRAVACAO"

        # 4. OLED DISPLAY UPDATE (ONLY WHEN ENABLED)
        if display_enabled:  # Conditional display refresh for power efficiency
            try:
                oled.fill(0)
                if screen == 0:
                    oled.text("--- TEMPS 1/2 ---", 5, 0)
                    oled.text(f"A(MPU):{tempA:.1f}C" if tempA is not None else "A:--", 0, 12)
                    oled.text(f"B(AHT):{tempB:.1f}C" if tempB is not None else "B:--", 0, 22)
                    oled.text(f"C(B280):{tempC:.1f}C" if tempC is not None else "C:--", 0, 32)
                    oled.text(f"D(B180):{tempD:.1f}C" if tempD is not None else "D:--", 0, 42)
                    oled.text(f"E(DS18):{tempE:.1f}C" if tempE is not None else "E:--", 0, 52)
                elif screen == 1:
                    oled.text("--- TEMPS 2/2 ---", 5, 0)
                    oled.text(f"F(NTC) :{tempF:.1f}C" if tempF is not None else "F:--", 0, 12)
                    oled.text(f"G(DHT) :{tempG:.1f}C" if tempG is not None else "G:--", 0, 22)
                    oled.text(f"Umd(AHT):{umidA:.1f}%" if umidA is not None else "UmdA:--", 0, 32)
                    oled.text(f"Umd(DHT):{umidB:.1f}%" if umidB is not None else "UmdB:--", 0, 42)
                    oled.text(f"Prs(B280):{pressA:.0f}" if pressA is not None else "PrsA:--", 0, 52)
                else:
                    oled.text("--- STATUS ---", 15, 0)
                    oled.text(f"Status: {log_status}", 0, 15)
                    oled.text(f"Registros: {record_count}", 0, 30)
                    uptime_s = time.ticks_diff(time.ticks_ms(), start_time) // 1000
                    mins = uptime_s // 60
                    hours = mins // 60
                    uptime_str = f"{hours:02d}:{(mins % 60):02d}:{(uptime_s % 60):02d}"
                    oled.text(f"Uptime: {uptime_str}", 0, 45)
                oled.show()
                screen = (screen + 1) % 3
            except Exception as e:
                # Display errors are non-critical - continue data acquisition
                pass

    except Exception as e:
        log_status = "ERRO FATAL"
        # Attempt to display fatal error message if display is enabled
        if display_enabled:
            try:
                oled.fill(0)
                oled.text("--- ERRO FATAL ---", 0, 20)
                oled.text("Reinicie o dispos.", 0, 40)
                oled.show()
            except:
                pass # Complete failure - no recovery possible
        break 
        
    # 5. INTER-CYCLE DELAY
    time.sleep(30) # 30-second sampling interval

# === SAFE SHUTDOWN AND SD CARD EJECTION PROTOCOL ===
try:
    os.umount('/sd')
    # 5-pulse LED sequence indicates safe removal state
    for _ in range(5):
        led.on()
        time.sleep(0.2)
        led.off()
        time.sleep(0.2)
except Exception as e:
    # Unmount failure - rapid LED pulse indicates unsafe state
    while True:
        led.toggle()
        time.sleep_ms(100)

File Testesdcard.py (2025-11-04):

# datalogger_rtc.py - Logs date and time to SD Card with safe eject button
import os
import machine
import time
from sdcard import SDCard

# --- Hardware Configuration ---

# Onboard LED for visual feedback
led = machine.Pin("LED", machine.Pin.OUT)

# Safe Eject Button on GP3
# Connection: One button pin -> GP3, other pin -> 3V3 (Pin 36)
eject_button = machine.Pin(3, machine.Pin.IN, machine.Pin.PULL_DOWN)

# SPI(1) Hardware Configuration - Physical Pins 14, 15, 16, 17
spi = machine.SPI(1,
                  baudrate=1000000,
                  sck=machine.Pin(10),
                  mosi=machine.Pin(11),
                  miso=machine.Pin(12))
cs = machine.Pin(13, machine.Pin.OUT)

# --- Initialization ---

print("Initializing logging system...")

# Mount SD card
try:
    sd = SDCard(spi, cs)
    os.mount(sd, '/sd')
    print("✓ SD card mounted successfully.")
except Exception as e:
    print(f"✗ Critical failure mounting SD card: {e}")
    print("Program will be terminated.")
    raise

# Initialize Real-Time Clock (RTC)
rtc = machine.RTC()

# IMPORTANT: On first run, uncomment the line below
# and adjust to current date and time to set the clock.
# Format: (year, month, day, weekday, hour, minute, second, microsecond)
# Example for August 25, 2025, 18:13:00 (Monday = 0)
# rtc.datetime((2025, 8, 25, 0, 18, 13, 0, 0))

# Define log file name
log_file_path = '/sd/timelog3.csv'

# Create file with header if it doesn't exist
try:
    with open(log_file_path, 'r') as f:
        pass # File already exists, do nothing
    print(f"✓ Using existing log file: {log_file_path}")
except OSError:
    # File doesn't exist, create it with header
    with open(log_file_path, 'w') as f:
        f.write("Timestamp\n")
    print(f"✓ New log file created: {log_file_path}")

print("\n--- LOGGING STARTED ---")
print("Press button on GP3 to safely unmount card.")

# --- Main Loop ---
while True:
    # Check if eject button was pressed
    if eject_button.value() == 1:
        print("\nEject button pressed. Finalizing...")
        break

    # Get current date and time from RTC
    current_time = rtc.datetime()
    
    # Format date and time as friendly string
    timestamp_str = "{:04d}-{:02d}-{:02d} {:02d}:{:02d}:{:02d}".format(
        current_time[0], current_time[1], current_time[2],
        current_time[4], current_time[5], current_time[6]
    )

    # Open file in append mode and save new line
    try:
        with open(log_file_path, 'a') as f:
            f.write(f"{timestamp_str}\n")
        
        # Blink LED quickly to indicate record was saved
        led.on()
        time.sleep_ms(50)
        led.off()
        
        print(f"Record saved: {timestamp_str}")

    except Exception as e:
        print(f"✗ Error saving to file: {e}")

    # Wait 5 seconds for next record
    time.sleep(5)

# --- Safe Shutdown and Ejection ---
print("\nUnmounting SD card filesystem...")
try:
    os.umount('/sd')
    print("✓ SD card safely unmounted!")
    
    # Blink LED 5 times to signal safe card removal
    for _ in range(5):
        led.on()
        time.sleep(0.2)
        led.off()
        time.sleep(0.2)
        
except Exception as e:
    print(f"✗ Error unmounting SD card: {e}")

print("Program terminated. Safe to remove card.")

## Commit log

2025-08-25 Adiciona sensor AHT20, BMP280 e MPU
2025-08-25 Resolve bug e adiciona BMP180
    [bmp280.py, main.py]
2025-08-30 Adiciona botao para ligar display
2025-11-04 refactor: translate comments to English and improve technical documentation
    [Schematic_Sensors.fzz, Schematic_protoboard.fzz]
2025-11-05 Add cleaned data BRT
    [inmet_weather_station_data_sep_2025_cleaned_BRT.csv, inmet_weather_station_data_sep_2025_utc.csv]
2025-11-06 Att validation code
    [inmet_weather_station_data_sep_2025_cleaned_BRT.csv, validation_and_Measured_Data_cleaned_BRT_.csv, validation_data_cleaned_BRT.csv]
2025-11-06 Adapt the code from Colab to Jupyter Notebook on VS Code.
    [inmet_weather_station_data_sep_2025_utc.csv, validation_and_Measured_Data_cleaned_BRT_.csv, validation_data_cleaned_BRT.csv]
2025-11-06 att Sensor_Comparison_and_Validation
2025-11-07 Add temperature and humidity drift analysis.
2025-11-10 Add drift analysis for pressure.
2025-11-14 Add a folder for prediction models
    [validation_and_Measured_Data_cleaned_BRT_.csv]
2025-11-16 Add: Train LSTM model using humidity and pressure data
2025-11-17 Add decision tree plots
    [validation_and_Measured_Data_cleaned_BRT_.csv]
2025-11-17 docs: add visualization graphs for LSTM temperature predictions
2025-11-18 Add time series decomposition analysis for temperature
2025-11-18 Add time series decomposition analysis for pressure
2025-11-19 Add FFT analysis for temperature sensors
2025-11-20 feat: add FFT analysis for humidity and pressure sensors
2025-11-20 Add moving average filter analysis for temperature sensors
2025-11-20 docs: add moving average filter theory and equations
2025-11-20 feat: add moving average filter analysis for humidity and pressure
2025-11-21 feat: add median filter analysis for temperature and humidity
2025-11-21 analysis: add pressure median filter and RMSE comparison
2025-11-27 feat: add EWMA filter analysis for temperature
2025-11-27 add EWMA filter theory and numerical example
2025-11-27 feat: add EWMA filter analysis for humidity
2025-11-27 feat: add EWMA filter analysis for pressure
2025-11-27 add EWMA filter for pressure and RMSE comparison
2025-11-27 organize digital filter graphs into graphs folder
2025-12-06 refactor: reorganize project structure
    [inmet_weather_station_data_sep_2025_utc.csv, validation_and_Measured_Data_cleaned_BRT_.csv, validation_data_cleaned_BRT.csv]
2025-12-06 docs: update Digital Filters description and image
2025-12-18 feat: add custom PCB design and documentation
2025-12-18 refactor: organize PCB firmware and add KY-028 NTC module support
2025-12-18 docs: update PCB documentation to reflect v1 status and errors
    [main.py]
